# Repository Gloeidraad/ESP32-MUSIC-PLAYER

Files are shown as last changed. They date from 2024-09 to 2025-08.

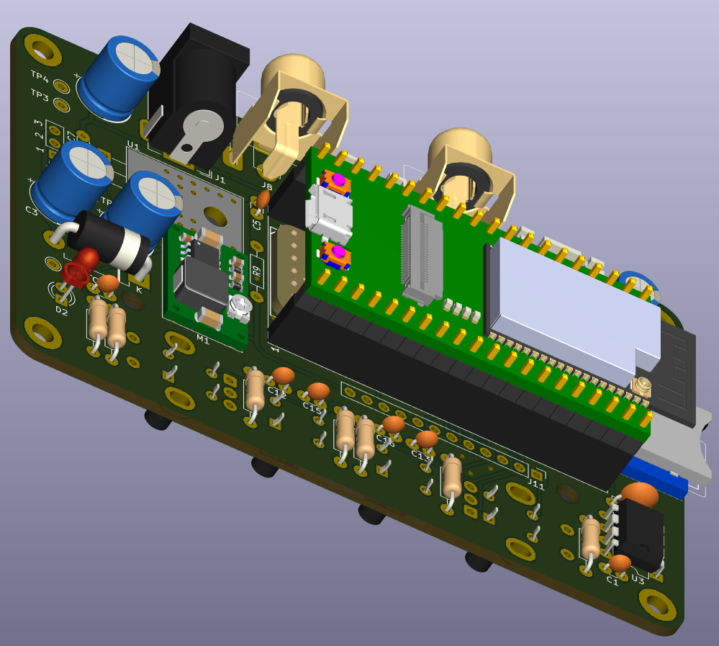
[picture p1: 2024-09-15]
Hardware/V1/Doc/Images/ESP32-MUSIC-PLAYER-V1-3D-2.png

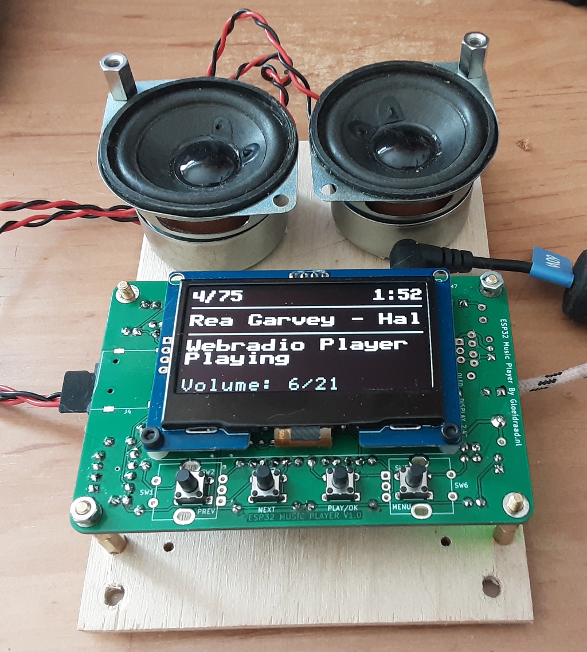
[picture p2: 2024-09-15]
Hardware/V1/Doc/Images/ESP32-MUSIC-PLAYER-V1-3D-DEMO.jpg

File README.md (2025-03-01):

# ESP32-MUSIC-PLAYER
SD-Card, Webradio, Bluetooth music player based on an ESP32 Wrover module

This is an MP3 player, Web-radio player, Bluetooth player, and simple waveform generator, based on an ESP32 WROVER module. The output can be either a line-out connection or an on-board 2 x 3W @ 4 ohms power ampifier. The output type can be chosen by mounting matching module(s).

This design is derived from my project "AM/FM-modulator-with-ESP32-module" (https://github.com/Gloeidraad/AMFM-modulator-with-ESP32-module). 

The PCB design has been made with KiCad 8.0. 

There at two versions of the design: 
Version 1.1 is mostly based on through hole components. It uses the I2C version of the 2.4 inch OLED display. Some examples can be found at: https://nl.aliexpress.com/item/1005006345983913.html choose the version with the connector on the top and left side of the display. It can be equipped with a PCM5102A Module for line out audio, or with one or two MAX98357A Module(s), allowing to connect directly to loudspeakers with a maximum power of 3 Watt per channel.  
The second version V1.5 is mostly based on 1206 SMD devices, and can be built into a cheap Strapubox 2515WS or the similar TRU COMPONENTS TC-2515 housing, available at https://www.conrad.com. This version uses the SPI version of 2.4 inch OLED display, and supports only audio line output via a PCM5102A Module. The display can also be found on : https://nl.aliexpress.com/item/1005006345983913.html but choose the version  the 7 pins connector on the left side of the display. This version can also be equipped with a SC card adapter, which allows the SD-card to be inserted next to the display. In addition, a nice front cover is available. Both the SD adapter and the front cover are included in the V1.5 design files.
The software will automatically detect, which display is attached, so there is only one version of the software. Please note, that the software supports only ASCII code page 437 (OEM-US, OEM 437, PC-8, or MS-DOS Latin US) up to character 0xAF, so if you enter names and titles with special characters, please be sure that the data is stored in this format. An example of the web radio play list can be found in the project.

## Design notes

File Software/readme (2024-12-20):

This sketch has been built with Arduino IDE 2.3.2 and ESP32 board package 2.0.17.

It should be no problem to use a newer or older IDE version, however these instructions
are for the 2.3.2 - 2.3.4 versions. Please note that the sketch will not run when
compiled with ESP32 board package 3.0.0 or higher.

Step 1: Download the Arduino IDE software from:
        https://www.arduino.cc/en/software
        (Possibly scroll down on the page for 2.3.2)
 
Step 2: Open Arduino IDE and install the ESP32 packages:
        https://randomnerdtutorials.com/installing-the-esp32-board-in-arduino-ide-windows-instructions/
        (Remark: the few seconds they mentioned to install the package is actually a couple of minutes, so be patient)

Step 3: Download the sketch, and make sure the whole
        project is inside the directory ESP32-Music-Player
        Open the directory and open project ESP32-Music-Player.ino
        
Step 4: Select the target board with menu:
        Tools => Board "xxx" => ESP32 Arduino => ESP32 Wrover Kit (all versions)
        
Step 5: Select the needed partition scheme with menu:
        Tools => Partition Scheme "xxx" => Huge APP (...)
        
Step 6: Switch on both “Show verbose output” checkboxes in menu:
        File => Preferences => tab Settings
        (Building the sketch takes a long time, so it is useful
        to monitor the progress)
        
Step 7: Connect the USB cable to the ESP32 module and make sure that
        the PC recognizes it as a serial port. If not, install the
        drivers for the corresponding serial adapter, normally
        CP2102,r CH340C, or CH9102
         
Step 8: Choose the port of the ESP32 module via menu:
        Tools => Port
         
Step 9: To see the debug info, you can open a serial monitor:
        Tools => Serial Monitor
        And set the baud rate to 115200
         
Step 10: Compile and upload the sketch:
         Sketch => Upload (or press the (->) button)
         It will take a while to compile the whole sketch,
         so have a little patience...
         
Step 11: You can monitor the messages from the sketch in the serial
         monitor, as long as the USB cable is connected. In addition,
         you can query some information by sending some simple commands.
         Send a ? to get a list of the commands.

Notes:

I used the following libaries for the project: 
 
https://github.com/schreibfaul1/ESP32-audioI2S/
https://github.com/pschatzmann/ESP32-A2DP
https://github.com/mathertel/OneButton

I included those used directories directly in the project. In the previous version
the libraries were installed separately, but it appeared that using a newer or older
versions of a library can lead to errors or unwanted behavior. Therefore, working
versions are included in the project (in subdirectory “src”). Please take care if
you plan to replace them with a different version.
          
Please report if you encounter any problems with the libraries.

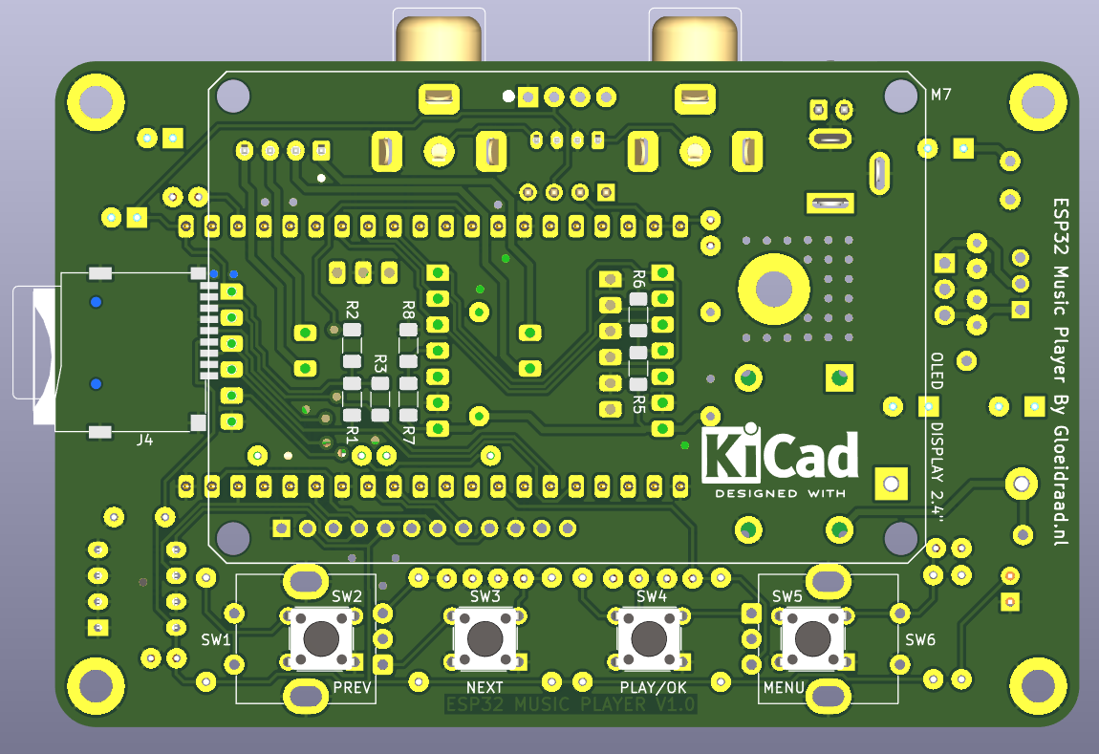
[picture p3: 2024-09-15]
Hardware/V1/Doc/Images/ESP32-MUSIC-PLAYER-V1-3D-BOT1.png

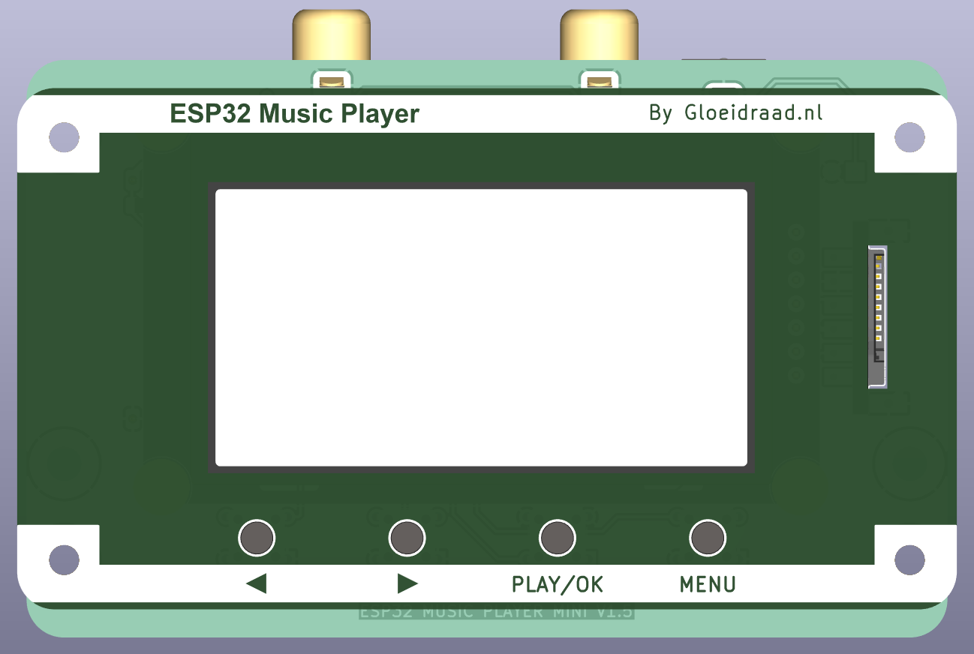
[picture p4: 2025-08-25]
Hardware/V5-SPI/ESP32-MUSIC-PLAYER-MINI-V5-PANEL/Images/assy front.png

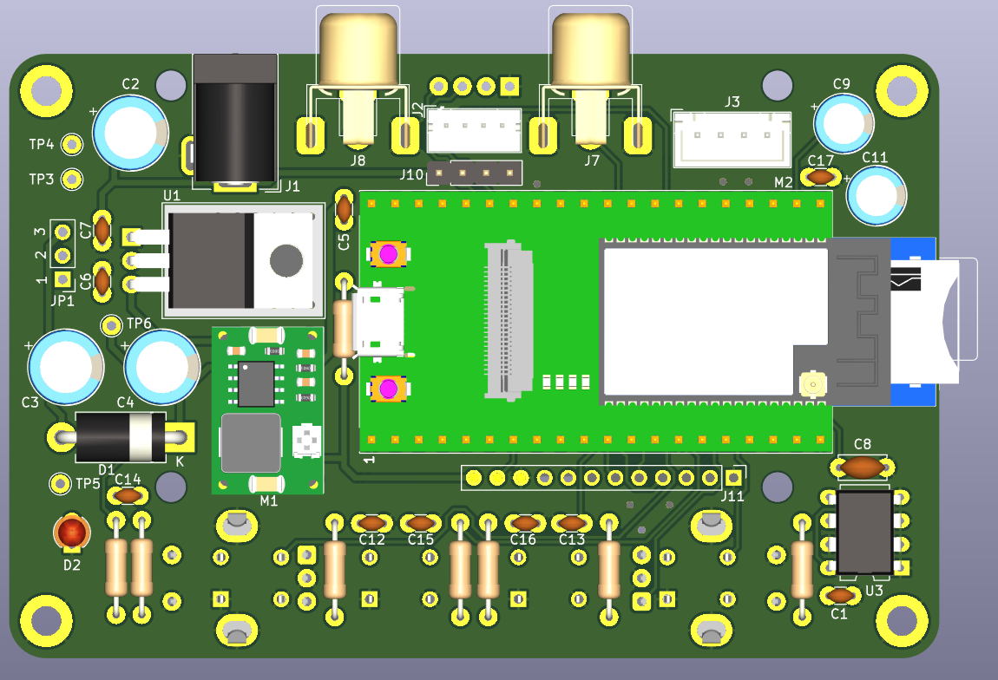
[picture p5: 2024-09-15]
Hardware/V1/Doc/Images/ESP32-MUSIC-PLAYER-V1-3D-TOP2.png

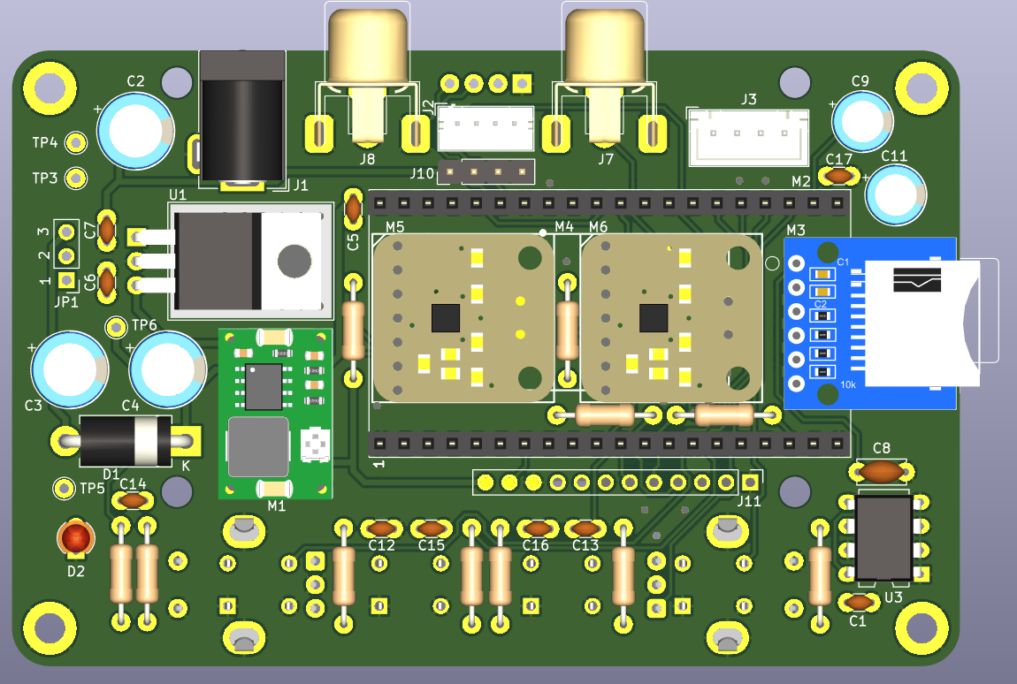
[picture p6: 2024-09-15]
Hardware/V1/Doc/Images/ESP32-MUSIC-PLAYER-V1-3D-TOP1.png

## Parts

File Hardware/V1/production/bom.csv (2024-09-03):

Designator | Footprint | Quantity | Value | LCSC Part #
C1, C5, C6, C7 | C_CER_D30_W16_P25_E20_H08 | 4 | 100n
C11, C9 | CE_Radial_D6.3mm_P2.50mm_E2.0mm | 2 | 10µF
C12, C13, C14, C15, C16, C17 | C_CER_D30_W16_P25_E20_H08 | 6 | 1n
C2, C3, C4 | CE_Radial_D8.0mm_P3.50mm_E2.0mm | 3 | 100µF
C8 | C_CER_D50_W25_P50_E20_H08 | 1 | 2u2
D1 | D_DO-201AD_P12.70mm_Horizontal | 1 | 1N5822
D2 | LED_D3.0mm | 1 | LED
J1 | BarrelJack_GCT_DCJ200-10-A_Horizontal | 1 | DC-IN
J10 | PinHeader_1x04_P2.54mm_Vertical | 1 | HDR4
J11 | PinHeader_1x12_P2.54mm_Vertical | 1 | EXP1
J2 | JST_PH_B4B-PH-K_1x04_P2.00mm_Vertical | 1 | JST PH4
J3 | JST_XH_B4B-XH-A_1x04_P2.50mm_Vertical | 1 | JST XH4
J4 | TF PUSH | 1 | SHOU-HAN-TF-PUSH | C393941
J7, J8 | Keystone RCA | 2 | Keystone 900
J9 | JST_EH_B2B-EH-A_1x02_P2.50mm_Vertical | 1 | Conn_01x02
JP1 | PinHeader_1x03_P2.54mm_Vertical | 1 | PSEL
M1 | MOD-DC-DC-DUAL | 1 | CN3903 5V/3A Module
M2 | ESP32-WROVER-DEV_ON_HEADERS_BARE | 1 | ESP32-WROVER-CAM-40P
M3 | MOD-USD-ADAPTER18X18 | 1 | µSD CARD MODULE
M4 | MOD-PCM5102A-TYPE2B | 1 | PCM5102A Module
M5, M6 | MOD-MAX98357A | 2 | MAX98357A Module
M7 | OLED128x64-2.4inch-i2c-top | 1 | OLED 2.4 inch
R1, R2, R3 | 1206 | 3 | 10k
R10 | R_Axial_L6.0mm_D2.0mm_P10.16mm_Horizontal | 1 | 560k
R11 | R_Axial_L6.0mm_D2.0mm_P10.16mm_Horizontal | 1 | 470R
R12, R13 | R_Axial_L6.0mm_D2.0mm_P10.16mm_Horizontal | 2 | 10k
R14, R16, R17, R18, R19, R20 | R_Axial_L6.0mm_D2.0mm_P10.16mm_Horizontal | 6 | 47k
R5, R6, R7, R8 | 1206 | 4 | NM
R9 | R_Axial_L6.0mm_D2.0mm_P10.16mm_Horizontal | 1 | 100k
SW1, SW6 | RotaryEncoder_Bourns_Vertical_PEC12R-3x17F-Sxxxx | 2 | RotaryEncoder_Switch
SW2, SW3, SW4, SW5 | SW_TH_Tactile_Omron_B3F-10xx | 4 | SW-PUSHBUT-6X6-V
TP3, TP4, TP5, TP6 | TestPoint_THTPad_D2.0mm_Drill1.0mm | 4 | TestPoint
U1 | TO-220-3_Horizontal_TabDown | 1 | L7818
U3 | DIP-SO-08_W7.62mm | 1 | 24LC64

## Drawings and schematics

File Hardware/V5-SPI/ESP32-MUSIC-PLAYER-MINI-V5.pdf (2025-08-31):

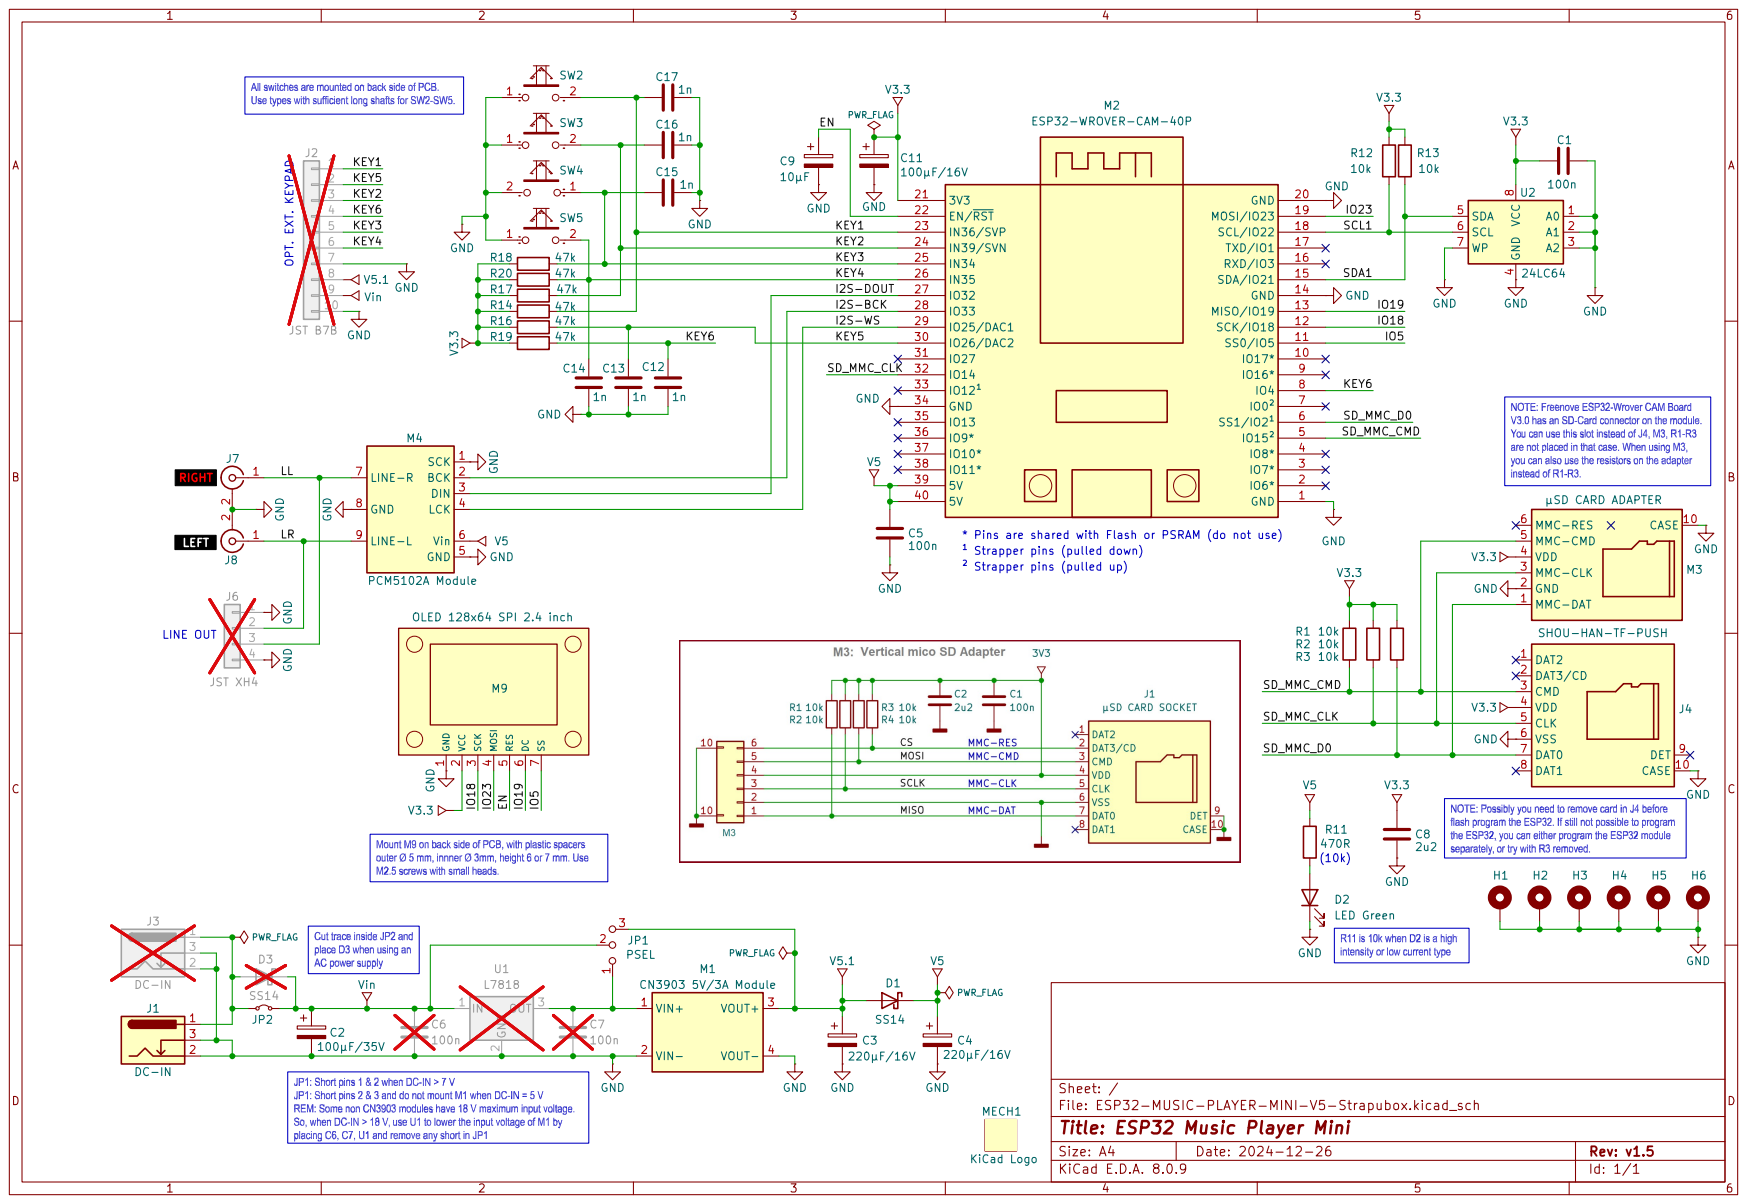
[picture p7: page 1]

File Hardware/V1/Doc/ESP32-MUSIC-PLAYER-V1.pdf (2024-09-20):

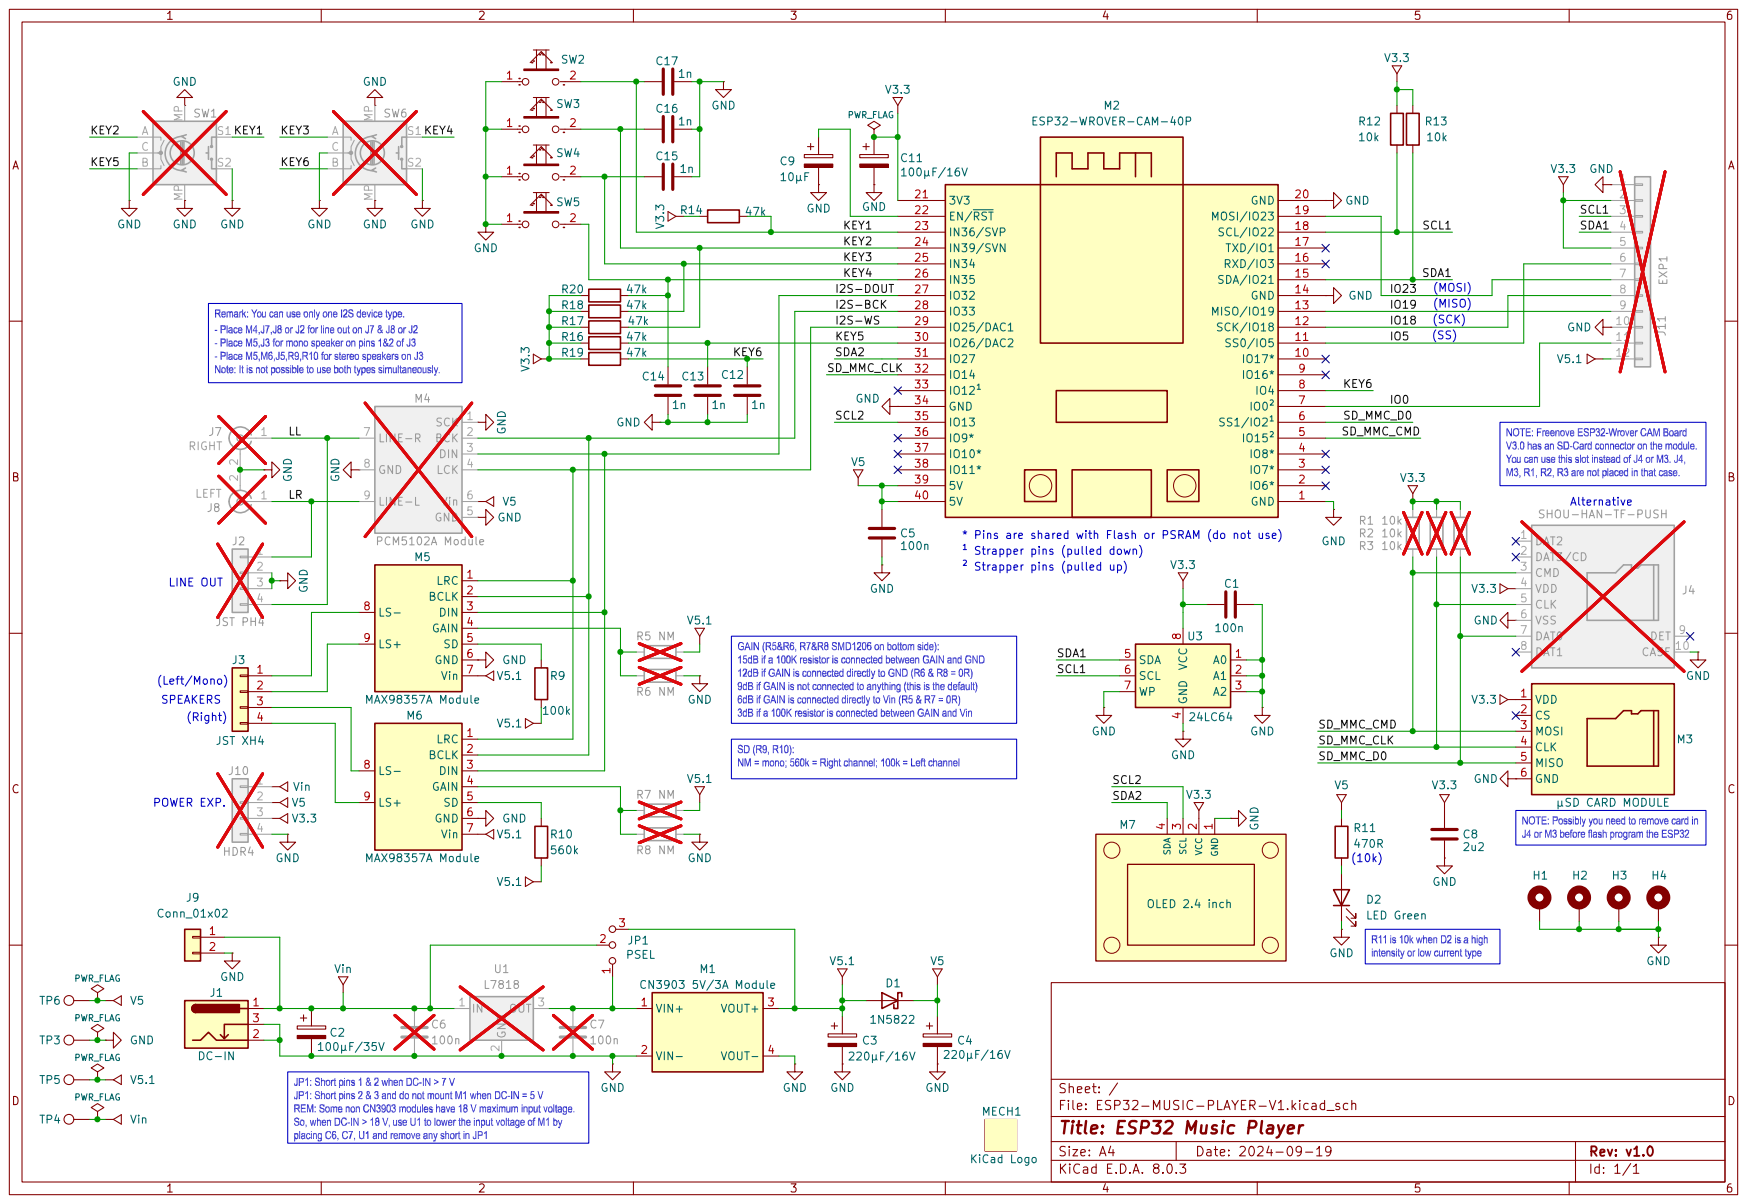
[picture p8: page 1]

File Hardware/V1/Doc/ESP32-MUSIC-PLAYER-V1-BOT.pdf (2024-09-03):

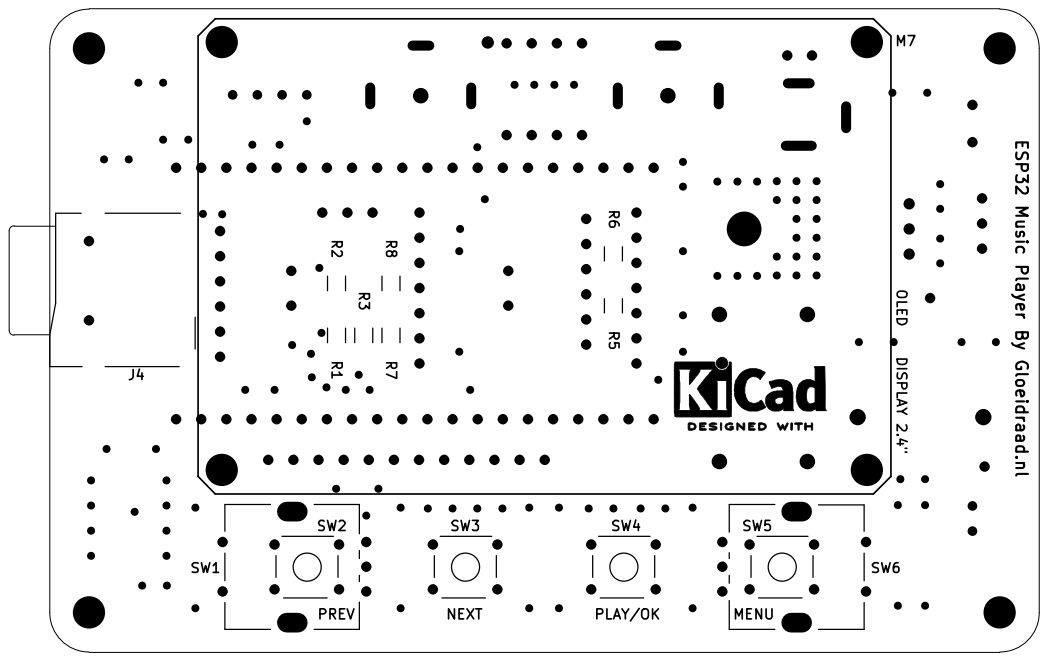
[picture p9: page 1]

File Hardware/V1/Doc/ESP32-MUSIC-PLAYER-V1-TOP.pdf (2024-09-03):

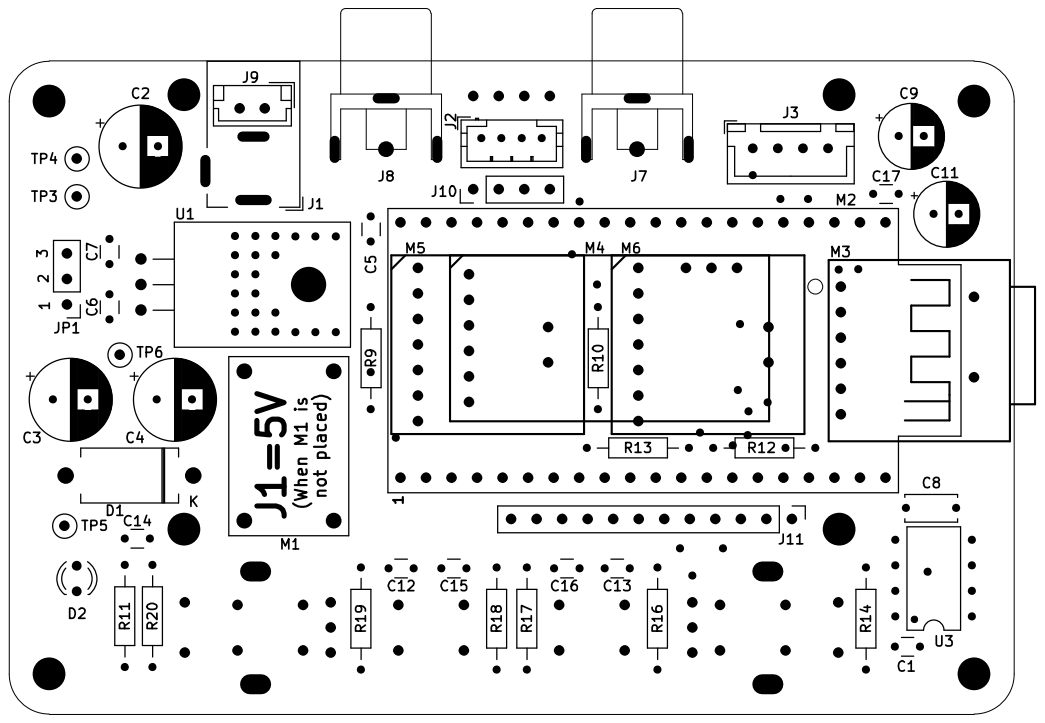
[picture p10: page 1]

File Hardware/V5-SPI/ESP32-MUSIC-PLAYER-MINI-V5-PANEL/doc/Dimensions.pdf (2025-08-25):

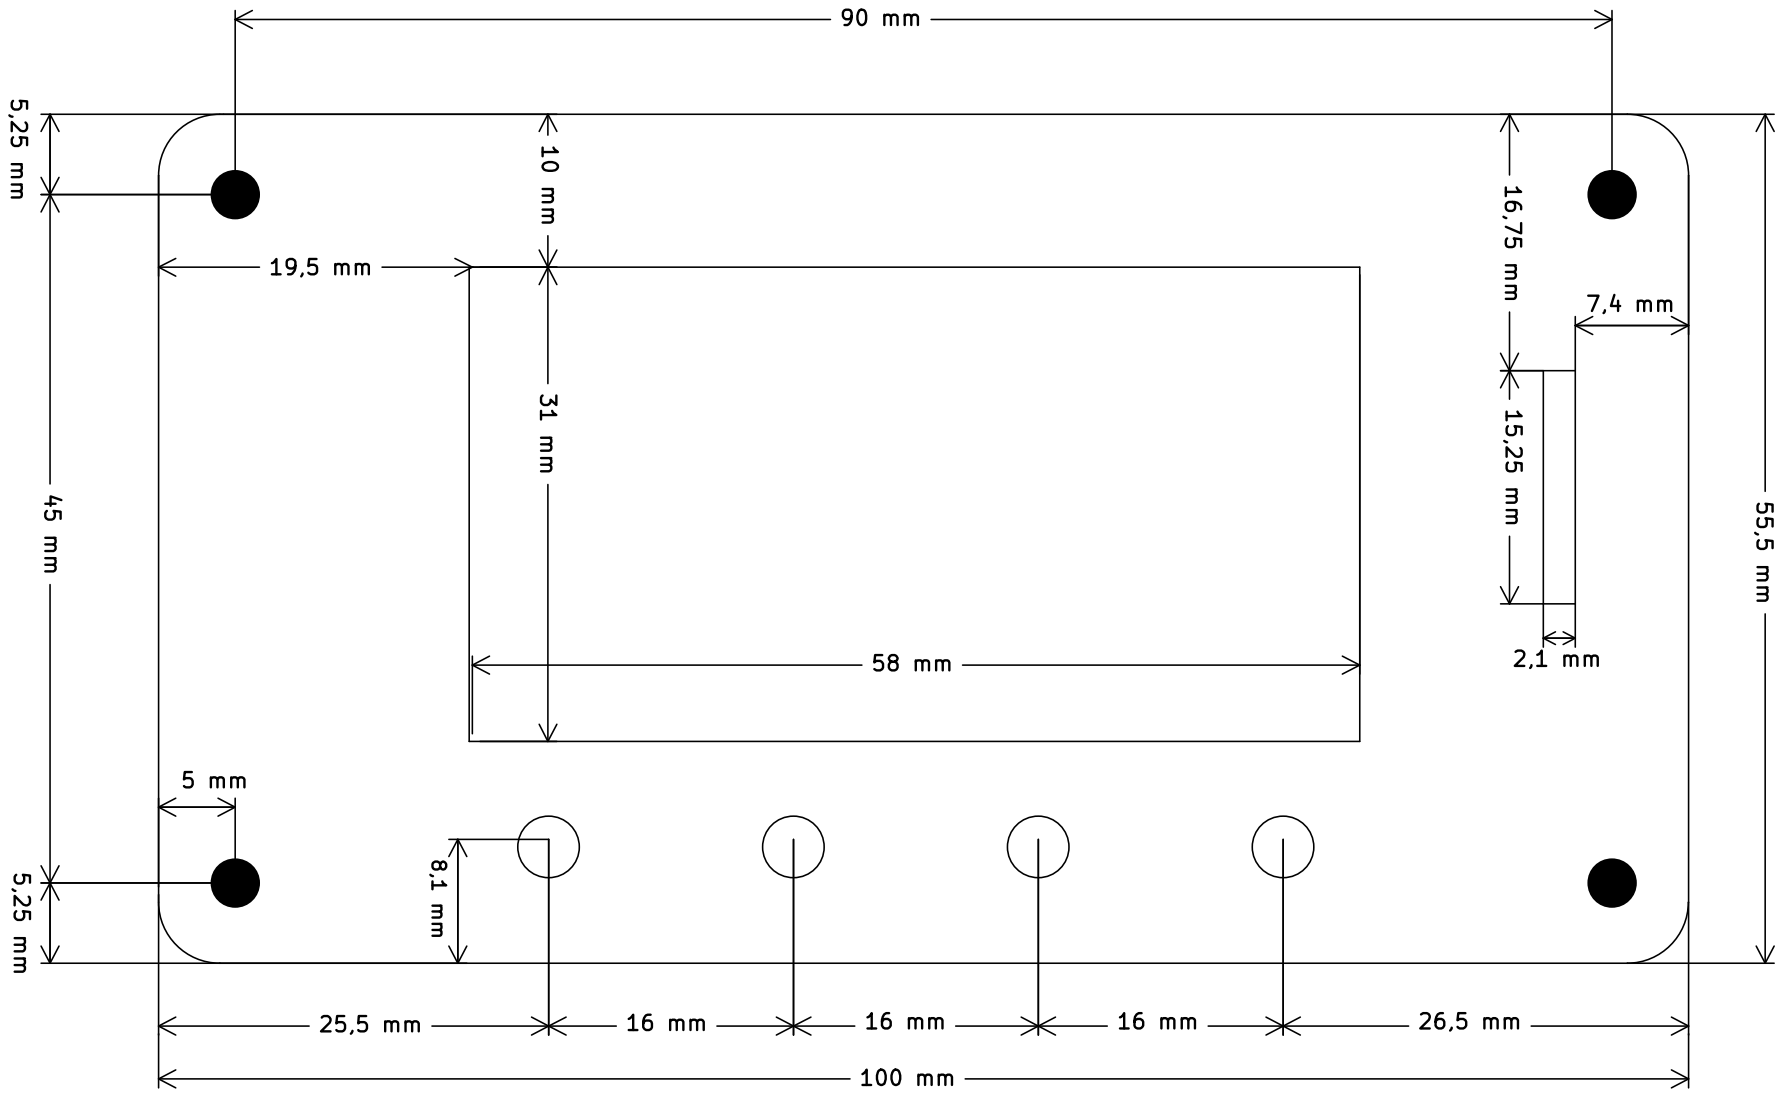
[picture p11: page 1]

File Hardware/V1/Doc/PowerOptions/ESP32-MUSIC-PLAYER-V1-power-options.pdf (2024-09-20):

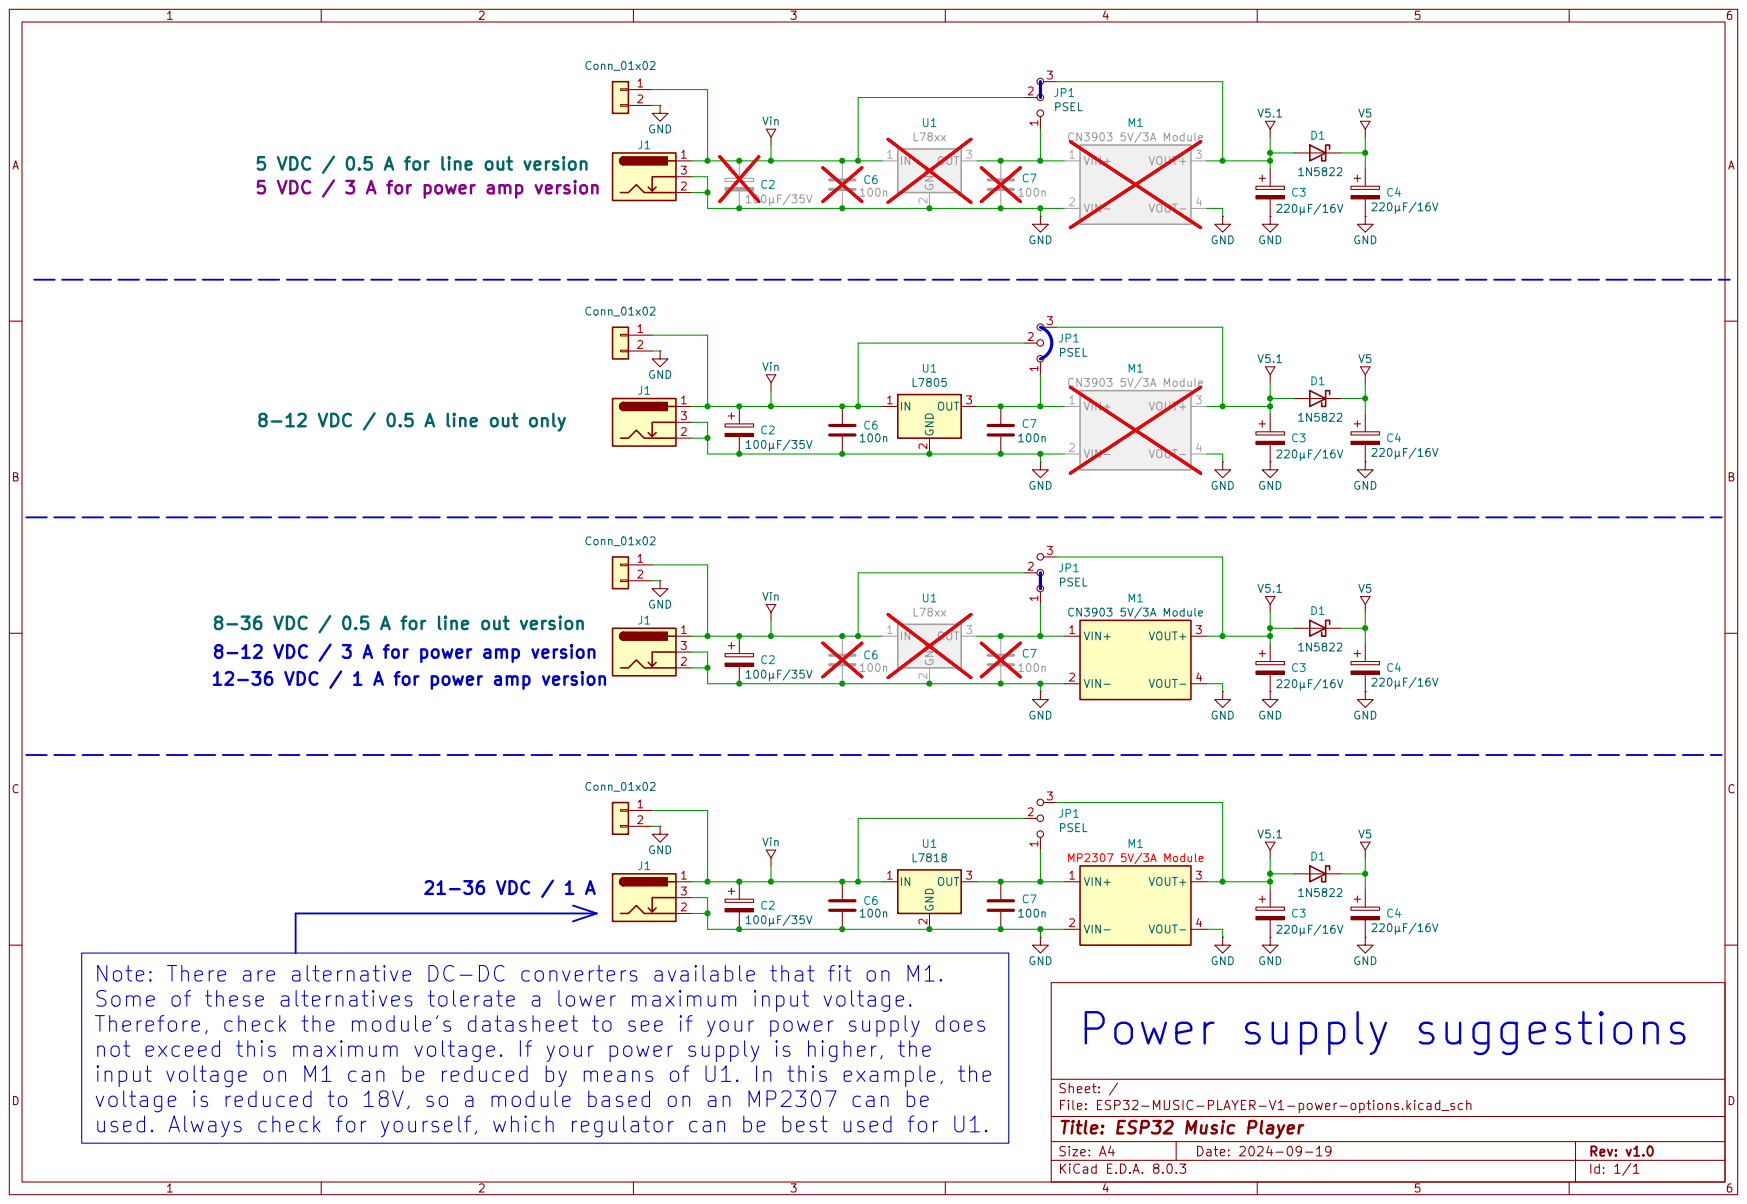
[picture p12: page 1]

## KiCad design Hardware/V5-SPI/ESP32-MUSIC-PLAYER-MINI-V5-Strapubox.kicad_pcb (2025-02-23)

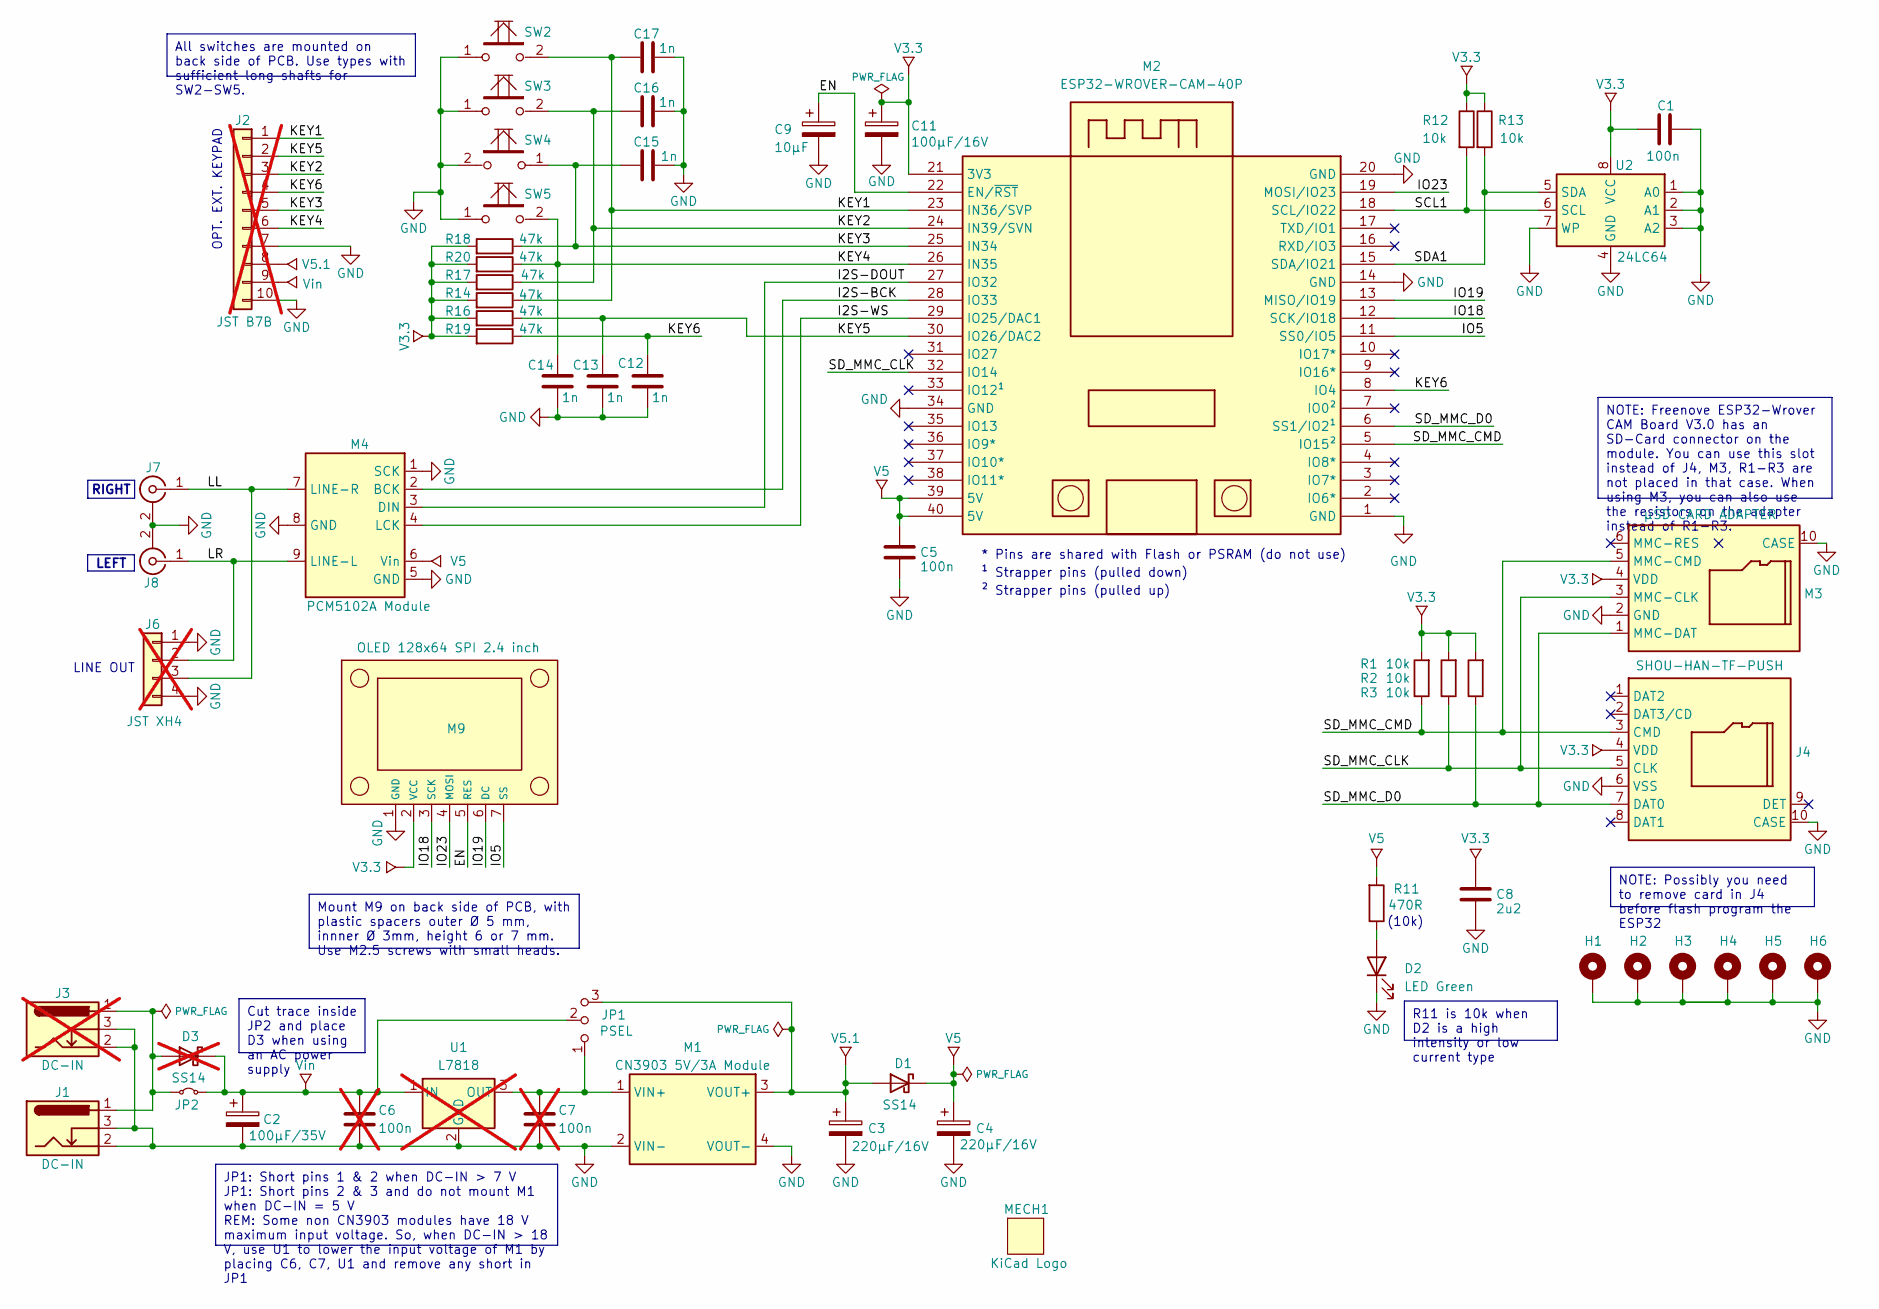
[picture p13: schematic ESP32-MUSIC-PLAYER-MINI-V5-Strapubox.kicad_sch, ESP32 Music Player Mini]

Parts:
C1, C5: 100n; C_1206_3216Metric_Pad1.33x1.80mm_HandSolder
C2: 100µF/35V; CE_Radial_D8.0mm_P3.50mm_E2.0mm
C3, C4: 220µF/16V; CE_Radial_D8.0mm_P3.50mm_E2.0mm
C6, C7: 100n; C_1206_3216Metric_Pad1.33x1.80mm_HandSolder; not fitted
C8: 2u2; C_1206_3216Metric_Pad1.33x1.80mm_HandSolder
C9: 10µF; CE_Radial_D6.3mm_P2.50mm_E2.0mm
C11: 100µF/16V; CE_Radial_D6.3mm_P2.50mm_E2.0mm
C12, C13, C14, C15, C16, C17: 1n; C_1206_3216Metric_Pad1.33x1.80mm_HandSolder
D1: SS14; DIODE_SMA
D2: LED Green; LED_D3.0mm
D3: SS14; DIODE_SMA; not fitted
H1, H2, H3, H4, H5, H6: MountingHole; MountingHole_3.7mm_Pad
J1: DC-IN; BarrelJack_GCT_DCJ200-10-A_Horizontal
J2: JST B7B; PinHeader_1x10_P2.54mm_Vertical; not fitted
J3: DC-IN; BarrelJack_GCT_DCJ200-10-A_Horizontal; not fitted
J4: SHOU-HAN-TF-PUSH; TF PUSH; JLC C393941
J6: JST XH4; JST_XH_B4B-XH-A_1x04_P2.50mm_Vertical; not fitted
J7, J8: Keystone 900; Keystone RCA
JP1: PSEL; SolderJumper-3_P1.3mm_Open_RoundedPad1.0x1.5mm
JP2: Jumper_2_Small_Bridged; SolderJumper-2_P1.3mm_Bridged_RoundedPad1.0x1.5mm
M1: CN3903 5V/3A Module; MOD-DC-DC-DUAL
M2: ESP32-WROVER-CAM-40P; ESP32-WROVER-DEV_ON_HEADERS_BARE
M3: µSD CARD ADAPTER; PinHeader_1x06_P2.54mm_SD_expander_socket_T3
M4: PCM5102A Module; MOD-PCM5102A-TYPE2B
M9: OLED 128x64 SPI 2.4 inch; OLED128x64-2.4inch-spi-type1
MECH1: KiCad Logo; KiCad-Logo2_6mm_SilkScreen
R1, R2, R3, R12, R13: 10k; R_1206_3216Metric_Pad1.30x1.75mm_HandSolder
R11: 470R; R_1206_3216Metric_Pad1.30x1.75mm_HandSolder
R14, R16, R17, R18, R19, R20: 47k; R_1206_3216Metric_Pad1.30x1.75mm_HandSolder
SW2, SW3, SW4, SW5: SW-PUSHBUT-6X6-V; SW_TH_Tactile_Omron_B3F-10xx
U1: L7818; TO-252-2; not fitted
U2: 24LC64; SO-8_3.9x4.9mm_P1.27mm

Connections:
/EN: C9.1, M2.22 (EN/~RST), M9.5 (RES)
/I2S-BCK: M2.28 (IO33), M4.2 (BCK)
/I2S-DOUT: M2.27 (IO32), M4.3 (DIN)
/I2S-WS: M2.29 (IO25/DAC1), M4.4 (LCK)
/IO5: M2.11 (SS0/IO5), M9.7 (SS)
/IO18: M2.12 (SCK/IO18), M9.3 (SCK)
/IO19: M2.13 (MISO/IO19), M9.6 (DC)
/IO23: M2.19 (MOSI/IO23), M9.4 (MOSI)
/KEY1: C17.1, J2.1, M2.23 (IN36/SVP), R14.1, SW2.2
/KEY2: C16.1, J2.3, M2.24 (IN39/SVN), R17.1, SW3.2
/KEY3: C15.1, J2.5, M2.25 (IN34), R18.1, SW4.1
/KEY4: C14.1, J2.6, M2.26 (IN35), R20.1, SW5.2
/KEY5: C13.1, J2.2, M2.30 (IO26/DAC2), R16.1
/KEY6: C12.1, J2.4, M2.8 (IO4), R19.1
/LL: J6.3, J7.1 (In), M4.7 (LINE-R)
/LR: J6.2, J8.1 (In), M4.9 (LINE-L)
/SCL1: M2.18 (SCL/IO22), R12.2, U2.6 (SCL)
/SDA1: M2.15 (SDA/IO21), R13.2, U2.5 (SDA)
/SD_MMC_CLK: J4.5 (CLK), M2.32 (IO14), M3.3 (MMC-CLK), R2.1
/SD_MMC_CMD: J4.3 (CMD), M2.5 (IO15²), M3.5 (MMC-CMD), R1.1
/SD_MMC_D0: J4.7 (DAT0), M2.6 (SS1/IO2¹), M3.1 (MMC-DAT), R3.1
GND: C1.2, C2.2, C3.2, C4.2, C5.2, C6.2, C7.2, C8.2, C9.2, C11.2, C12.2, C13.2, C14.2, C15.2, C16.2, C17.2, D2.1 (K), H1.1, H2.1, H3.1, H4.1, H5.1, H6.1, J1.2, J1.3, J2.7, J2.10, J3.2, J3.3, J4.6 (VSS), J4.10 (CASE), J6.1, J6.4, J7.2 (Ext), J8.2 (Ext), M1.2 (VIN-), M1.4 (VOUT-), M2.1 (GND), M2.14 (GND), M2.20 (GND), M2.34 (GND), M3.2 (GND), M3.10 (CASE), M4.1 (SCK), M4.5 (GND), M4.8 (GND), M9.1 (GND), SW2.1, SW3.1, SW4.2, SW5.1, U1.2 (GND), U2.1 (A0), U2.2 (A1), U2.3 (A2), U2.4 (GND), U2.7 (WP)
unnamed: D2.2 (A), R11.1
unnamed: D3.2 (A), J1.1, J3.1, JP2.1 (A)
unnamed: C7.1, JP1.1 (A), M1.1 (VIN+), U1.3 (OUT)
V3.3: C1.1, C8.1, C11.1, J4.4 (VDD), M2.21 (3V3), M3.4 (VDD), M9.2 (VCC), R1.2, R2.2, R3.2, R12.1, R13.1, R14.2, R16.2, R17.2, R18.2, R19.2, R20.2, U2.8 (VCC)
V5: C4.1, C5.1, D1.1 (K), M2.39 (5V), M2.40 (5V), M4.6 (Vin), R11.2
V5.1: C3.1, D1.2 (A), J2.8, JP1.3 (B), M1.3 (VOUT+)
Vin: C2.1, C6.1, D3.1 (K), J2.9, JP1.2 (C), JP2.2 (B), U1.1 (IN)

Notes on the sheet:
R11 is 10k when D2 is a high intensity or low current type
NOTE: Possibly you need to remove card in J4 before flash program the ESP32
All switches are mounted on back side of PCB. Use types with sufficient long shafts for SW2-SW5.
Mount M9 on back side of PCB, with plastic spacers outer Ø 5 mm, innner Ø 3mm, height 6 or 7 mm. Use M2.5 screws with small heads.
NOTE: Freenove ESP32-Wrover CAM Board V3.0 has an SD-Card connector on the module. You can use this slot instead of J4, M3, R1-R3 are not placed in that case. When using M3, you can also use the resistors on the adapter instead of R1-R3.
Cut trace inside JP2 and place D3 when using an AC power supply
JP1: Short pins 1 & 2 when DC-IN > 7 V JP1: Short pins 2 & 3 and do not mount M1 when DC-IN = 5 V REM: Some non CN3903 modules have 18 V maximum input voltage. So, when DC-IN > 18 V, use U1 to lower the input voltage of M1 by placing C6, C7, U1 and remove any short in JP1
² Strapper pins (pulled up)
* Pins are shared with Flash or PSRAM (do not use)
LINE OUT
OPT. EXT. KEYPAD
¹ Strapper pins (pulled down)
RIGHT
(10k)
LEFT

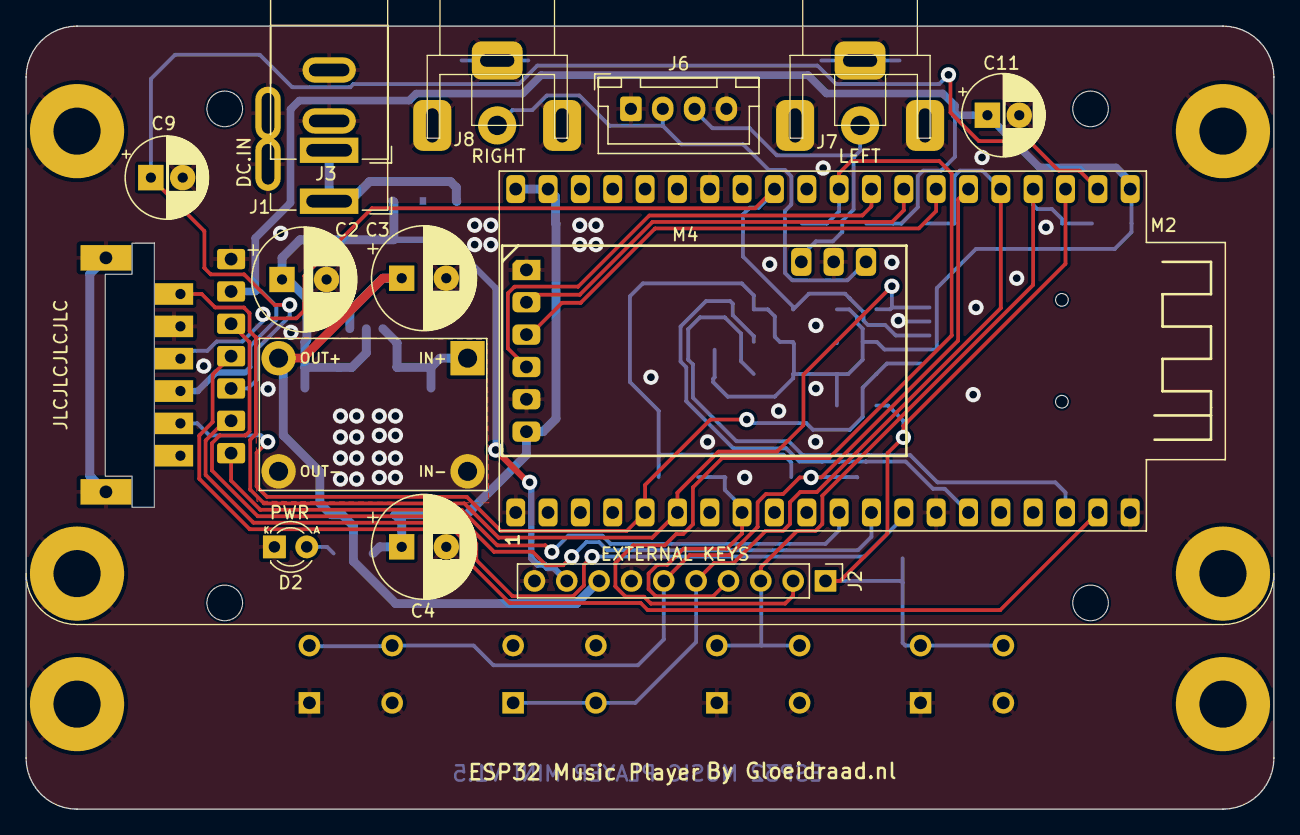
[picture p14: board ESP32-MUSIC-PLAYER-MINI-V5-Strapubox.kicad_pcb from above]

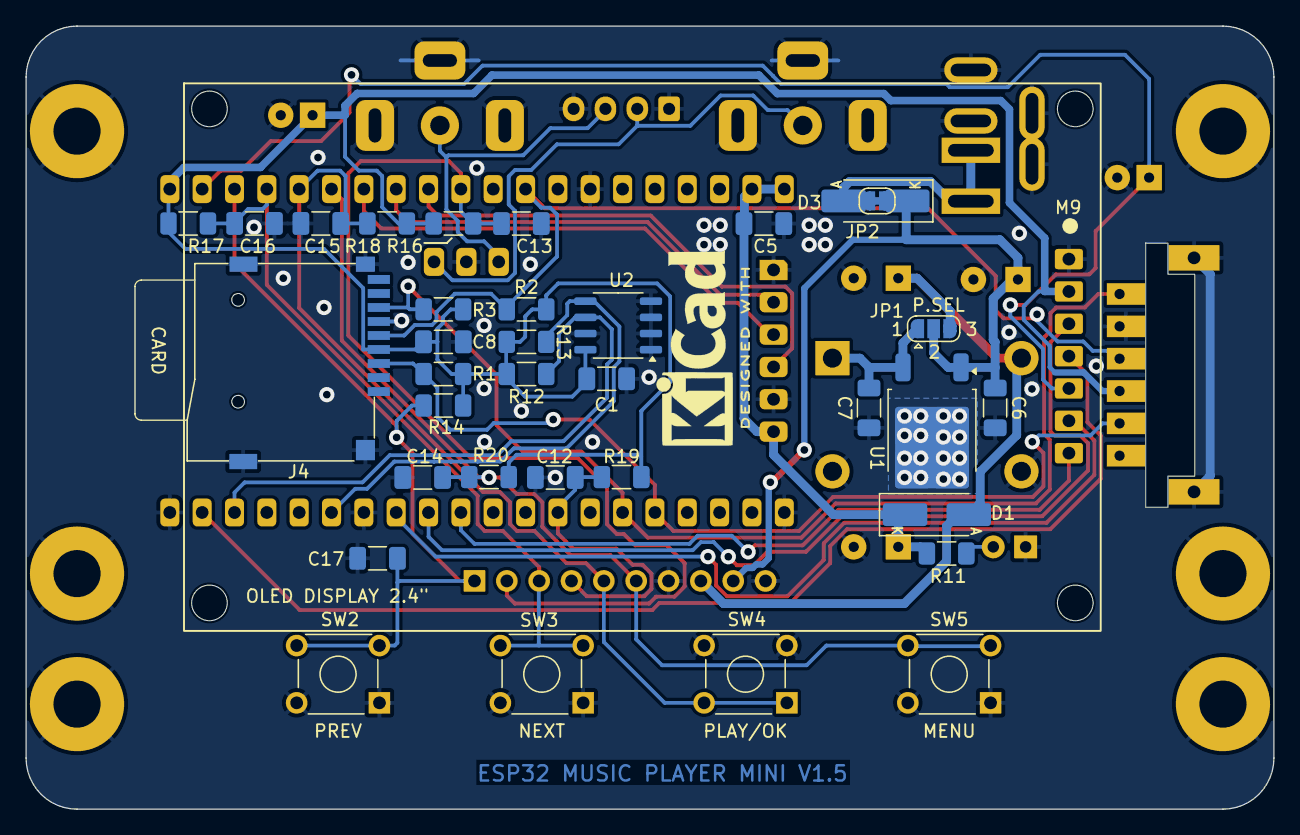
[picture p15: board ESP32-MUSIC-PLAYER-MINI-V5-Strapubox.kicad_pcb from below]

Board: 2 copper layers, 98.0 x 61.5 mm, 58 parts (37 on the bottom side), 29 nets.

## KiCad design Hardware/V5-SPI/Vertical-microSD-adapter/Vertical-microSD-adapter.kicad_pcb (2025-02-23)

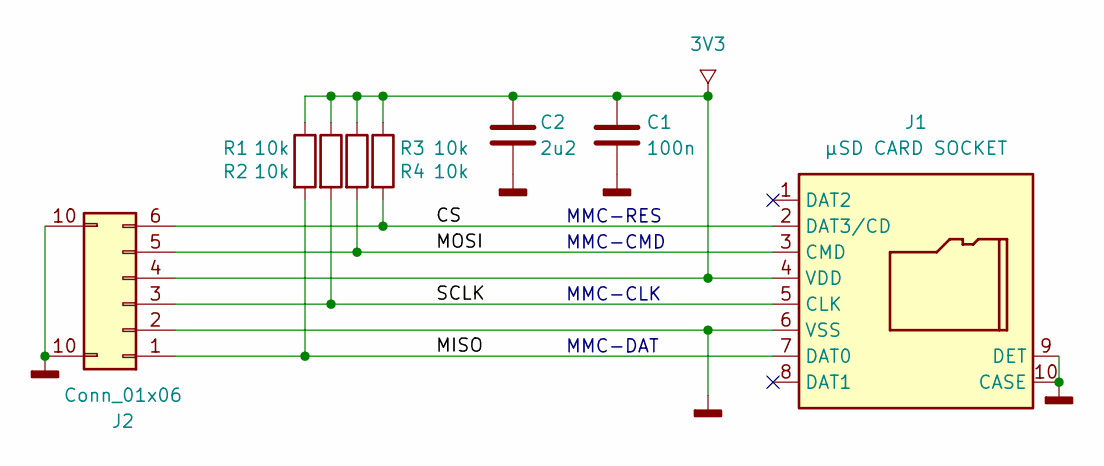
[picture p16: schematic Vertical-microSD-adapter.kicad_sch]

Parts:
C1: 100n; C_0603_1608Metric_Pad1.08x0.95mm_HandSolder
C2: 2u2; C_0805_2012Metric_Pad1.18x1.45mm_HandSolder
J1: µSD CARD SOCKET; TF PUSH
J2: Conn_01x06; PinHeader_1x06_P2.54mm_SD_expander
R1, R2, R3, R4: 10k; R_0603_1608Metric_Pad0.98x0.95mm_HandSolder

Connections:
3V3: C1.1, C2.1, J1.4 (VDD), J2.4, R1.1, R2.1, R3.1, R4.1
/CS: J1.2 (DAT3/CD), J2.6, R4.2
/MISO: J1.7 (DAT0), J2.1, R1.2
/MOSI: J1.3 (CMD), J2.5, R3.2
/SCLK: J1.5 (CLK), J2.3, R2.2
GNDD: C1.2, C2.2, J1.6 (VSS), J1.9 (DET), J1.10 (CASE), J2.2, J2.10 (Pin_10a)

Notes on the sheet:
MMC-CMD
MMC-DAT
MMC-CLK
MMC-RES

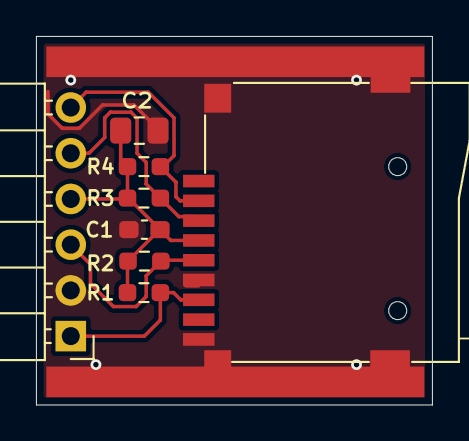
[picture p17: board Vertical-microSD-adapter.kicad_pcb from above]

Board: 2 copper layers, 22.0 x 20.5 mm, 8 parts (0 on the bottom side), 6 nets.

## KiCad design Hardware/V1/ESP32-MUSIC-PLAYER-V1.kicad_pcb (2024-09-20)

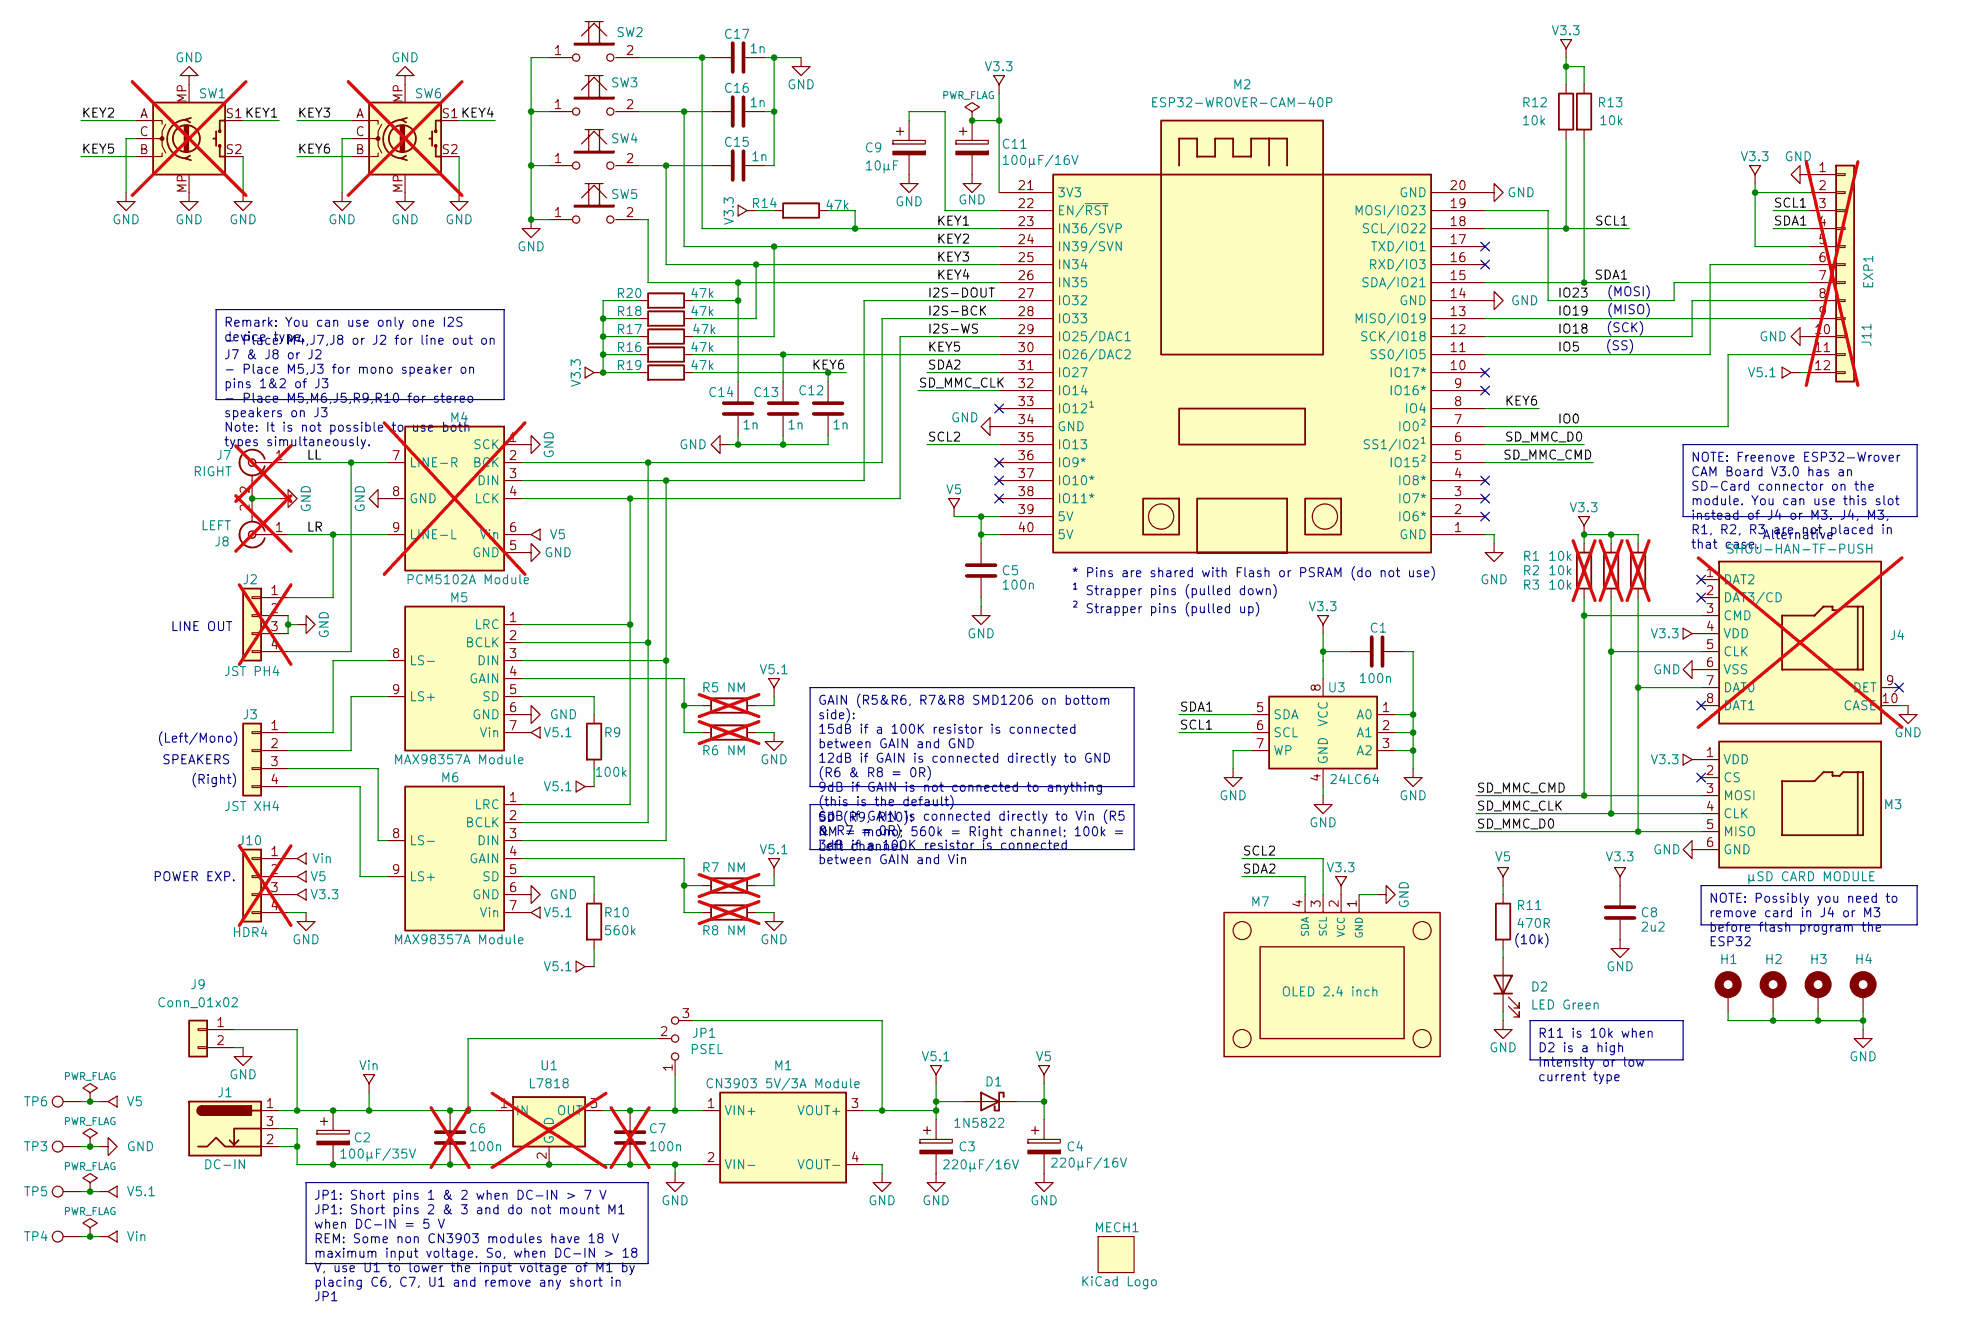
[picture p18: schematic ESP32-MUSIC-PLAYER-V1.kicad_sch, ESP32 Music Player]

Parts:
C1, C5: 100n; C_CER_D30_W16_P25_E20_H08
C2: 100µF/35V; CE_Radial_D8.0mm_P3.50mm_E2.0mm
C3, C4: 220µF/16V; CE_Radial_D8.0mm_P3.50mm_E2.0mm
C6, C7: 100n; C_CER_D30_W16_P25_E20_H08; not fitted
C8: 2u2; C_CER_D50_W25_P50_E20_H08
C9: 10µF; CE_Radial_D6.3mm_P2.50mm_E2.0mm
C11: 100µF/16V; CE_Radial_D6.3mm_P2.50mm_E2.0mm
C12, C13, C14, C15, C16, C17: 1n; C_CER_D30_W16_P25_E20_H08
D1: 1N5822; D_DO-201AD_P12.70mm_Horizontal
D2: LED Green; LED_D3.0mm
H1, H2, H3, H4: MountingHole; MountingHole_3.2mm_M3_DIN965_Pad
J1: DC-IN; BarrelJack_GCT_DCJ200-10-A_Horizontal
J2: JST PH4; JST_PH_B4B-PH-K_1x04_P2.00mm_Vertical; not fitted
J3: JST XH4; JST_XH_B4B-XH-A_1x04_P2.50mm_Vertical
J4: SHOU-HAN-TF-PUSH; TF PUSH; JLC C393941; not fitted
J7, J8: Keystone 900; Keystone RCA; not fitted
J9: Conn_01x02; JST_EH_B2B-EH-A_1x02_P2.50mm_Vertical
J10: HDR4; PinHeader_1x04_P2.54mm_Vertical; not fitted
J11: EXP1; PinHeader_1x12_P2.54mm_Vertical; not fitted
JP1: PSEL; PinHeader_1x03_P2.54mm_Vertical
M1: CN3903 5V/3A Module; MOD-DC-DC-DUAL
M2: ESP32-WROVER-CAM-40P; ESP32-WROVER-DEV_ON_HEADERS_BARE
M3: µSD CARD MODULE; MOD-USD-ADAPTER18X18
M4: PCM5102A Module; MOD-PCM5102A-TYPE2B; not fitted
M5, M6: MAX98357A Module; MOD-MAX98357A
M7: OLED 2.4 inch; OLED128x64-2.4inch-i2c-top
MECH1: KiCad Logo; KiCad-Logo2_6mm_SilkScreen
R1, R2, R3: 10k; R_1206_3216Metric_Pad1.30x1.75mm_HandSolder; not fitted
R5, R6, R7, R8: NM; R_1206_3216Metric_Pad1.30x1.75mm_HandSolder; not fitted
R9: 100k; R_Axial_L6.0mm_D2.0mm_P10.16mm_Horizontal
R10: 560k; R_Axial_L6.0mm_D2.0mm_P10.16mm_Horizontal
R11: 470R; R_Axial_L6.0mm_D2.0mm_P10.16mm_Horizontal
R12, R13: 10k; R_Axial_L6.0mm_D2.0mm_P10.16mm_Horizontal
R14, R16, R17, R18, R19, R20: 47k; R_Axial_L6.0mm_D2.0mm_P10.16mm_Horizontal
SW1, SW6: RotaryEncoder_Switch; RotaryEncoder_Bourns_Vertical_PEC12R-3x17F-Sxxxx; not fitted
SW2, SW3, SW4, SW5: SW-PUSHBUT-6X6-V; SW_TH_Tactile_Omron_B3F-10xx
TP3, TP4, TP5, TP6: TestPoint; TestPoint_THTPad_D2.0mm_Drill1.0mm
U1: L7818; TO-220-3_Horizontal_TabDown; not fitted
U3: 24LC64; DIP-SO-08_W7.62mm

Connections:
/I2S-BCK: M2.28 (IO33), M4.2 (BCK), M5.2 (BCLK), M6.2 (BCLK)
/I2S-DOUT: M2.27 (IO32), M4.3 (DIN), M5.3 (DIN), M6.3 (DIN)
/I2S-WS: M2.29 (IO25/DAC1), M4.4 (LCK), M5.1 (LRC), M6.1 (LRC)
/IO0: J11.11, M2.7 (IO0²)
/IO5: J11.6, M2.11 (SS0/IO5)
/IO18: J11.8, M2.12 (SCK/IO18)
/IO19: J11.9, M2.13 (MISO/IO19)
/IO23: J11.7, M2.19 (MOSI/IO23)
/KEY1: C17.1, M2.23 (IN36/SVP), R14.1, SW1.S1, SW2.2
/KEY2: C16.1, M2.24 (IN39/SVN), R17.1, SW1.A, SW3.2
/KEY3: C15.1, M2.25 (IN34), R18.1, SW4.2, SW6.A
/KEY4: C14.1, M2.26 (IN35), R20.1, SW5.2, SW6.S1
/KEY5: C13.1, M2.30 (IO26/DAC2), R16.1, SW1.B
/KEY6: C12.1, M2.8 (IO4), R19.1, SW6.B
/LL: J2.4, J7.1 (In), M4.7 (LINE-R)
/LR: J2.1, J8.1 (In), M4.9 (LINE-L)
/SCL1: J11.3, M2.18 (SCL/IO22), R12.2, U3.6 (SCL)
/SCL2: M2.35 (IO13), M7.3 (SCL)
/SDA1: J11.4, M2.15 (SDA/IO21), R13.2, U3.5 (SDA)
/SDA2: M2.31 (IO27), M7.4 (SDA)
/SD_MMC_CLK: J4.5 (CLK), M2.32 (IO14), M3.4 (CLK), R2.1
/SD_MMC_CMD: J4.3 (CMD), M2.5 (IO15²), M3.3 (MOSI), R1.1
/SD_MMC_D0: J4.7 (DAT0), M2.6 (SS1/IO2¹), M3.5 (MISO), R3.1
GND: C1.2, C2.2, C3.2, C4.2, C5.2, C6.2, C7.2, C8.2, C9.2, C11.2, C12.2, C13.2, C14.2, C15.2, C16.2, C17.2, D2.1 (K), H1.1, H2.1, H3.1, H4.1, J1.2, J1.3, J2.2, J2.3, J4.6 (VSS), J4.10 (CASE), J7.2 (Ext), J8.2 (Ext), J9.2, J10.4, J11.1, J11.10, M1.2 (VIN-), M1.4 (VOUT-), M2.1 (GND), M2.14 (GND), M2.20 (GND), M2.34 (GND), M3.6 (GND), M4.1 (SCK), M4.5 (GND), M4.8 (GND), M5.6 (GND), M6.6 (GND), M7.1 (GND), R6.2, R8.2, SW1.C, SW1.MP, SW1.S2, SW2.1, SW3.1, SW4.1, SW5.1, SW6.C, SW6.MP, SW6.S2, TP3.1, U1.2 (GND), U3.1 (A0), U3.2 (A1), U3.3 (A2), U3.4 (GND), U3.7 (WP)
unnamed: D2.2 (A), R11.2
unnamed: J3.1, M5.8 (LS-)
unnamed: J3.2, M5.9 (LS+)
unnamed: J3.3, M6.8 (LS-)
unnamed: J3.4, M6.9 (LS+)
unnamed: C7.1, JP1.1 (A), M1.1 (VIN+), U1.3 (OUT)
unnamed: C9.1, M2.22 (EN/~RST)
unnamed: M5.4 (GAIN), R5.1, R6.1
unnamed: M5.5 (SD), R9.1
unnamed: M6.4 (GAIN), R7.1, R8.1
unnamed: M6.5 (SD), R10.1
V3.3: C1.1, C8.1, C11.1, J4.4 (VDD), J10.3, J11.2, J11.5, M2.21 (3V3), M3.1 (VDD), M7.2 (VCC), R1.2, R2.2, R3.2, R12.1, R13.1, R14.2, R16.2, R17.2, R18.2, R19.2, R20.2, U3.8 (VCC)
V5: C4.1, C5.1, D1.1 (K), J10.2, M2.39 (5V), M2.40 (5V), M4.6 (Vin), R11.1, TP6.1
V5.1: C3.1, D1.2 (A), J11.12, JP1.3 (B), M1.3 (VOUT+), M5.7 (Vin), M6.7 (Vin), R5.2, R7.2, R9.2, R10.2, TP5.1
Vin: C2.1, C6.1, J1.1, J9.1, J10.1, JP1.2 (C), TP4.1, U1.1 (IN)

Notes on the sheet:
R11 is 10k when D2 is a high intensity or low current type
NOTE: Possibly you need to remove card in J4 or M3 before flash program the ESP32
Remark: You can use only one I2S device type.
GAIN (R5&R6, R7&R8 SMD1206 on bottom side): 15dB if a 100K resistor is connected between GAIN and GND 12dB if GAIN is connected directly to GND (R6 & R8 = 0R) 9dB if GAIN is not connected to anything (this is the default) 6dB if GAIN is connected directly to Vin (R5 & R7 = 0R) 3dB if a 100K resisto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
NOTE: Freenove ESP32-Wrover CAM Board V3.0 has an SD-Card connector on the module. You can use this slot instead of J4 or M3. J4, M3, R1, R2, R3 are not placed in that case.
- Place M4,J7,J8 or J2 for line out on J7 & J8 or J2 - Place M5,J3 for mono speaker on pins 1&2 of J3 - Place M5,M6,J5,R9,R10 for stereo speakers on J3 Note: It is not possible to use both types simultaneously.
SD (R9, R10): NM = mono; 560k = Right channel; 100k = Left channel
JP1: Short pins 1 & 2 when DC-IN > 7 V JP1: Short pins 2 & 3 and do not mount M1 when DC-IN = 5 V REM: Some non CN3903 modules have 18 V maximum input voltage. So, when DC-IN > 18 V, use U1 to lower the input voltage of M1 by placing C6, C7, U1 and remove any short in JP1
Alternative
² Strapper pins (pulled up)
* Pins are shared with Flash or PSRAM (do not use)
LINE OUT
(MISO)
(SS)
POWER EXP.
¹ Strapper pins (pulled down)
(SCK)
(10k)
(Right)
(MOSI)
SPEAKERS
(Left/Mono)

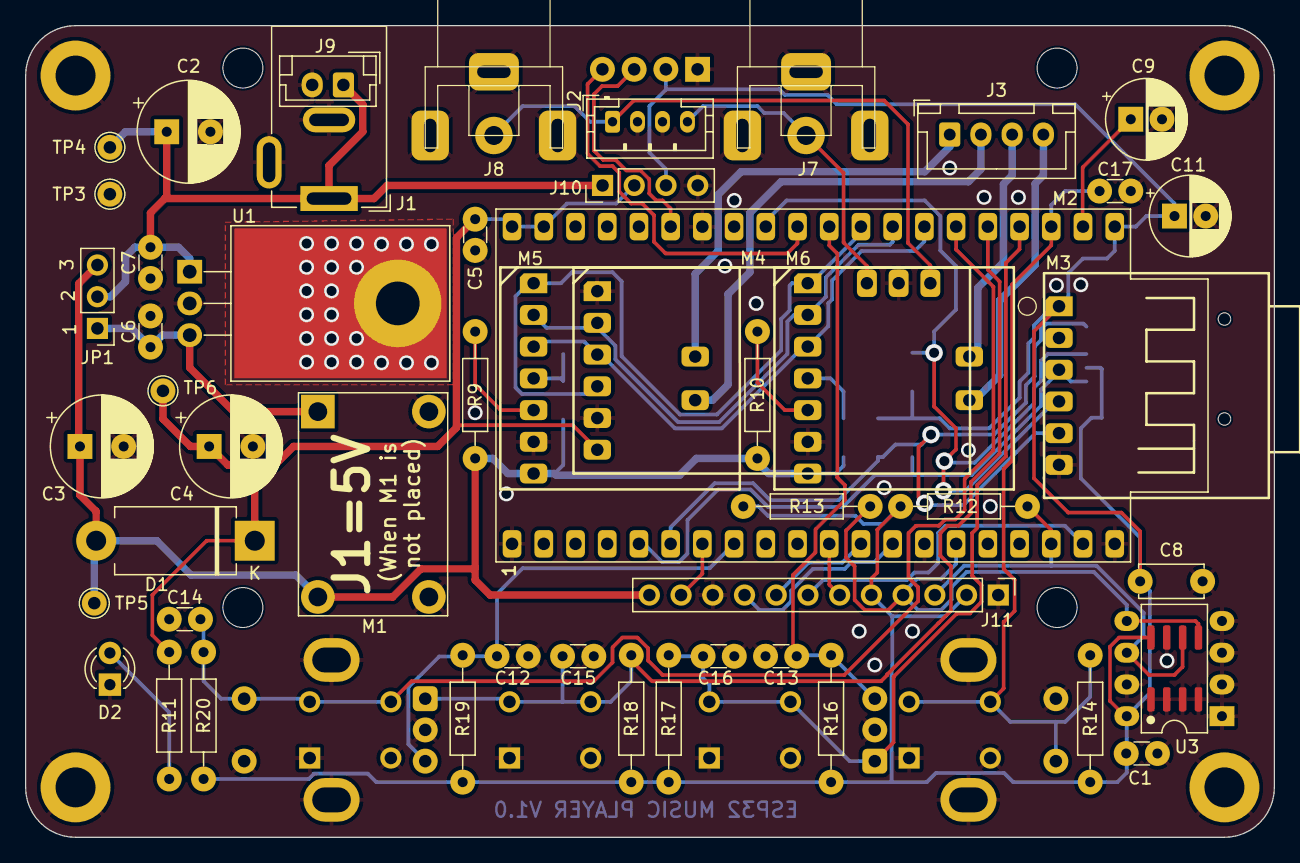
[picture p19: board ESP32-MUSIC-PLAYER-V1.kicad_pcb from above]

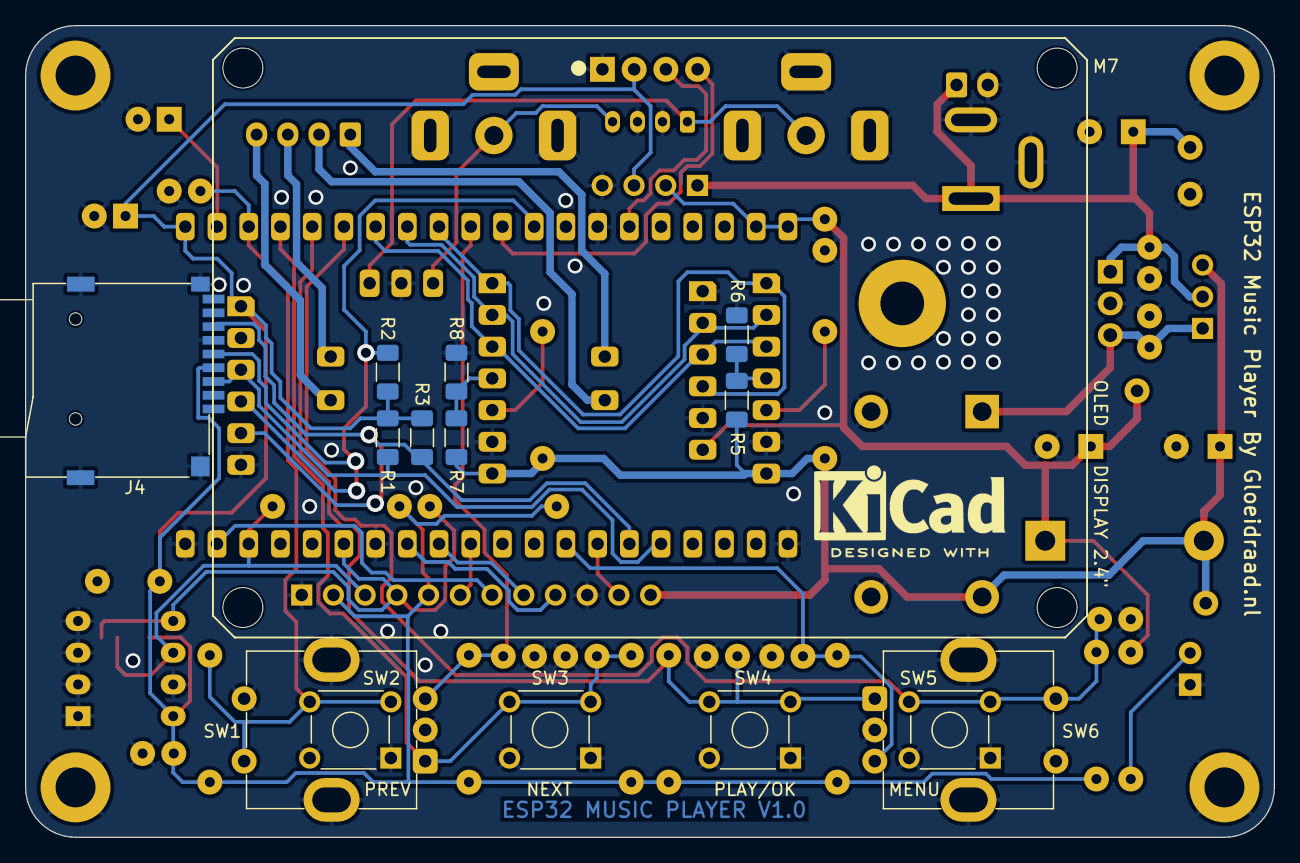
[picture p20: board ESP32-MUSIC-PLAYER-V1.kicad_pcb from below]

Board: 2 copper layers, 100.0 x 65.0 mm, 70 parts (16 on the bottom side), 39 nets.

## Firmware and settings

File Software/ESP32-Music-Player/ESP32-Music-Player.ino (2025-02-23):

// Increase size:
// https://github.com/espressif/arduino-esp32/issues/1906

#include <esp_idf_version.h>

#if ESP_IDF_VERSION < ESP_IDF_VERSION_VAL(5, 0, 0)  // ESP32 board package 3.0.0 or newer
  #warning unpack "AudioI2S-bsp-2xx.zip"       in directory "src"
  #warning unpack "BluetoothA2DP-bsp-2xx.zip"  in directory "src"
#else
  #warning unpack "AudioI2S-bsp-3xx.zip"       in directory "src"
  #warning unpack "BluetoothA2DP-bsp-3xx.zip"  in directory "src"
#endif

#include "src/AudioI2S/Audio.h"
#include "src/OneButton/OneButton.h"
#include "src/Hardware/board.h"
#include "src/Hardware/SSD1306.h"
#include "src/settings.h"
#include "src/ChipInfo.h" 
#include "src/I2C_Scanner.h"

#include "Player.h"
#include "Display.h"
#include "SimpleWaveGenerator.h"
#include "Gui.h"

SettingsClass      Settings(I2C_PORT_EEPROM, I2C_LOW_CLOCK_SPEED);

SsidSettingsClass  SsidSettings;
UrlSettingsClass   UrlSettings;
TrackSettingsClass TrackSettings;

PlayerClass        Player;
DisplayClass       Display;

SimpleWaveGeneratorClass WaveGenerator;

#define BLUETOOTH_FILE_NAME "bluetooth.ini"
#define SSID_FILE_NAME      "ssid.ini"
#define WEBRADIO_FILE_NAME  "webradio.ini"

OneButton SW1(PIN_SW1);
OneButton SW2(PIN_SW2);
OneButton SW3(PIN_SW3);
OneButton SW4(PIN_SW4);
OneButton SW5(PIN_SW5);

static void PrintWifiInfo() {
  char s[64];
   //WiFi.printDiag(Serial);
  sprintf(s, "WiFi TX level: %d (max %d = %sdB)", WiFi.getTxPower(), Settings.GetWifiTxLevel(), Settings.GetWifiTxLevelDB());
  Serial.println(s);
}

void SetWifiPower(int pwr, bool force = false) {
  if(!force && (pwr < 0 || pwr == Settings.NV.WifiTxIndex || pwr > SET_WIFI_TX_MAX)) {
    pwr = Settings.NV.WifiTxIndex;
    Serial.print("Wifi TX Power stays at ");
  }
  else {
    Settings.NV.WifiTxIndex = pwr;
    Serial.print("Changing Wifi TX Power to ");
    if (Settings.NV.SourceAF == SET_SOURCE_WEB_RADIO)
      WiFi.setTxPower((wifi_power_t)Settings.GetWifiTxLevel());
  }
  Serial.printf("entry %d (value %d = %sdB)\n",pwr, Settings.GetWifiTxLevel(), Settings.GetWifiTxLevelDB());
}

//=====================================================================//
//== Local: serial_command parser (for debugging purposes)           ==//
//=====================================================================//

static struct {
  const char * shortname;
  const char * longname;
  bool suppress_help;
} serial_command_list[] = {
  { "?",      "help"            , false }, // 0
  { "s",      "settings"        , false }, // 1
  { "rl",     "radiolist"       , false }, // 2
  { "rlr",    "radiolistraw"    , false }, // 3
  { "ssid",   "ssid"            , false }, // 4
  { "ssidpw", "ssidpassword"    , true  }, // 5
  { "tl",     "tracklist"       , false }, // 6
  { "pi",     "playinfo"        , false }, // 7
  { "sd",     "sd-card"         , false }, // 8
  { "wr",     "webradio"        , false }, // 9
  { "wf",     "waveform"        , false }, // 10
  { "bt",     "bluetooth"       , false }, // 11
  { "res",    "softreset"       , false }, // 12
  { "pw",     "printwaveform"   , false }, // 13
  { "pwh",    "printwaveformhex", false }, // 14
  { "sys",    "systeminfo"      , false }, // 15
  { "oled",   "oled-display"    , false }, // 16
  { "wifi",   "wifi-status"     , false }, // 17
  { "tx",     "wifi-tx-power"   , false }, // 18
  { "vol",    "volume"          , false }, // 19
  { "pp",     "play/pause"      , false }, // 20
  { "next",   "nexttrack"       , false }, // 21
  { "prev",   "prevtrack"       , false }, // 22
};

static void serial_command_help(void) {
  Serial.println("Short   | Long");
  Serial.println("--------|-------------");
  for (int i = 0; i < sizeof(serial_command_list) / sizeof(serial_command_list[0]); i++)
    if (!serial_command_list[i].suppress_help)
      Serial.printf("%-8s| %s\n", serial_command_list[i].shortname, serial_command_list[i].longname);
}

static int find_command_match(String &r) {
  for(int i = sizeof(serial_command_list) / sizeof(serial_command_list[0]) - 1; i >= 0 ; i--) {
    if(r.startsWith(serial_command_list[i].shortname) || r.startsWith(serial_command_list[i].longname)) {
      int len = r.indexOf(' ');
      if(len > 0) 
        r = r.substring(len + 1);
      return i;
    }
  }
  return -1;
}

static void change_player(uint8_t old_id, uint8_t new_id);

static void parse_command(String &r) { 
  r.trim();
  r.toLowerCase();
  int len = r.indexOf(' ');
  Serial.print("SERIAL COMMAND: ");
  Serial.println(r);
  switch(find_command_match(r)) {
    case  0: serial_command_help();     break;
    case  1: Settings.Print();          break;
    case  2: UrlSettings.Print(false);  break;
    case  3: UrlSettings.Print(true);   break;
    case  4: SsidSettings.Print(false); break;
    case  5: SsidSettings.Print(true);  break;
    case  6: TrackSettings.Print();     break;
    case  7: Player.SD_PrintDebug();    break;
    case  8: change_player(Settings.GetCurrentSourceId(), SET_SOURCE_SD_CARD);   break;
    case  9: change_player(Settings.GetCurrentSourceId(), SET_SOURCE_WEB_RADIO); break;
    case 10: change_player(Settings.GetCurrentSourceId(), SET_SOURCE_WAVE_GEN);  break;
    case 11: change_player(Settings.GetCurrentSourceId(), SET_SOURCE_BLUETOOTH); break;
    case 12: Settings.doSoftRestart();    break;
    case 13: Player.WP_PrintDebug(false); break;
    case 14: Player.WP_PrintDebug(true);  break;
    case 15: PrintChipInfo(0x0F);         break;
    case 16: OLED.Print();                break;
    case 17: PrintWifiInfo();             break;
    case 18: SetWifiPower(r.toInt());     break;
    case 19: { int vol = r.toInt();
               if(vol > 0)
                 Player.SetVolume(vol);
             }
             break;
    case 20: if(Settings.FirstTime) {
               Serial.println("FIRST TIME");    
               Settings.FirstSong = 1;
               Player.Play();
               Settings.FirstTime = 0;
             }
             else
               Player.PauseResume();
             break;
    case 21: Player.PlayNext();     break;
    case 22: Player.PlayPrevious(); break;
    default: Serial.println("Unknown Command"); break;
  }
}

//=====================================================================
//== Local: Timestamps
//=====================================================================

class TimeStampClass {
  public:
    TimeStampClass();
    void Update(void);
    uint32_t GetStamp10ms(void) { return timestamp_10ms;    }
    uint32_t GetStamp1sec(void) { return timestamp_1sec;    } 
    bool     Get10msTick(void)  { return ten_ms_tick;       }
    bool     GetSecondTick()    { return second_tick;       }
    bool     Get4SecTick()      { return four_seconds_tick; }
  private:
    uint64_t timestamp_us_prev;
    uint16_t timestamp_1sec_cnt;
    uint32_t timestamp_10ms;
    uint32_t timestamp_1sec;
    bool     ten_ms_tick;
    bool     second_tick;
    bool     four_seconds_tick;
};

TimeStampClass::TimeStampClass() {
  timestamp_10ms          = 0;
  timestamp_1sec          = 0;
  ten_ms_tick             = false;
  second_tick             = false;
  four_seconds_tick       = false;
  timestamp_us_prev       = 0;
  timestamp_1sec_cnt      = 0;
}

void TimeStampClass::Update(void) {
  uint64_t timestamp_us = esp_timer_get_time();
  ten_ms_tick             = false;
  second_tick             = false;
  four_seconds_tick       = false;
  if(timestamp_us - timestamp_us_prev >= TIMESTAMP_10MS_DIV) {
    timestamp_10ms++;
    timestamp_1sec_cnt++;
    timestamp_us_prev += TIMESTAMP_10MS_DIV;
    if(timestamp_us - timestamp_us_prev < TIMESTAMP_10MS_DIV) // supress multiple ticks 
      ten_ms_tick = true; 
    if(timestamp_1sec_cnt == 100) {
      timestamp_1sec++;
      timestamp_1sec_cnt = 0;
      second_tick = true;
      four_seconds_tick = !(timestamp_1sec & 3);
    }
  }
}

TimeStampClass TimeStamps;

//=====================================================================//
//== Local: Read setup and track data from SD Card                   ==//
//=====================================================================//

// MMC-SD: see https://github.com/espressif/arduino-esp32/tree/master/libraries/SD_MMC/src

static bool ReadSetupFromCard(bool get_init_data = true) {
  if(Settings.NV.SourceAF == SET_SOURCE_WAVE_GEN) return true; // Nothing to load for waveform player
  #ifdef USE_SD_MMC
    if(!SD_MMC.begin( "/sdcard", true)) {
      Serial.println("Card Mount Failed, using SSID & Radio lists from EEPROM");
      Settings.NoCard = 1;
      return false;
    }
  #else
    if (!SD.begin(PIN_SPI_SS, SPI, SPI_SD_SPEED)) {
      Serial.println("Card Mount Failed, using SSID & Radio lists from EEPROM");
      Settings.NoCard = 1;
      return false;
    }
  #endif
  Serial.println("Card Mount Succeeded");
  Settings.NoCard = 0;
  switch(Settings.NV.SourceAF) {
    case SET_SOURCE_SD_CARD   : TrackSettings.LoadFromCard();
                                break;
    case SET_SOURCE_WEB_RADIO : if(!SsidSettings.LoadFromCard(SSID_FILE_NAME))
                                  Serial.println("Using SSID list from EEPROM");
                                if(!UrlSettings.LoadFromCard(WEBRADIO_FILE_NAME))
                                  Serial.println("Using web station list from EEPROM");
                                break;
    case SET_SOURCE_BLUETOOTH : if(!Settings.LoadFromCard(BLUETOOTH_FILE_NAME))
                                  Serial.println("Using Bluetooth ID from EEPROM");
                                break;
  }
  #ifdef USE_SD_MMC
    SD_MMC.end(); // webradio doesn't like a mounted SD Card
  #else
    SD_MMC.end(); // webradio doesn't like a mounted SD Card
  #endif
  return true;
}

//=====================================================================//
//== Local: change player                                            ==//
//=====================================================================//

static void change_player(uint8_t old_id, uint8_t new_id) {
  if(new_id != old_id) {
    Serial.print("Change Player from \"");
    Serial.print(Settings.GetSourceName(old_id));
    Serial.print("\" to \"");
    Serial.print(Settings.GetSourceName(new_id));
    Serial.println("\"");
    Player.Stop();
    Settings.Play = 0;
    Settings.NV.SourceAF = new_id;
    Display.ShowBaseScreen(DISPLAY_HELP_PLEASE_WAIT);
    delay(100); // Give threads in Stop() some time to die out properly
    Settings.doSoftRestart();
  }
}

static void change_player(bool prev) {
  uint8_t CurrentSourceId = Settings.GetCurrentSourceId();
  if(prev) Settings.PrevPlayer();
  else     Settings.NextPlayer();
  change_player(CurrentSourceId, Settings.GetCurrentSourceId());
}

//=====================================================================//
//== Local: Loop function for Settings (keeps audio running)         ==//
//=====================================================================//

void SettingsLoopFunction(void) { Player.loop(); }

//=====================================================================//
//== Local: Button handlers                                          ==//
//=====================================================================//

static void GUI_Handler(uint8_t key) {
  if(key != 0xFF) Serial.printf("Button %d pressed: ", key);
  #if 1
  switch(GuiCallback(key)) {
    case GUI_RESULT_NEW_TRACK      : Player.PlayNew();      break;
    case GUI_RESULT_NEXT_PLAY      : Player.PlayNext();     break;
    case GUI_RESULT_PREV_PLAY      : Player.PlayPrevious(); break;
    case GUI_RESULT_PAUSE_PLAY     : if(Settings.FirstTime) {
                                       Serial.println("FIRST TIME");    
                                       Settings.FirstSong = 1;
                                       Player.Play();
                                       Settings.FirstTime = 0;
                                     }
                                     else
                                       Player.PauseResume();
                                     break;
    case GUI_RESULT_SEEK_PLAY      : Player.PositionEntry(); break;
    //case GUI_RESULT_STOP_PLAY    : break;
    //case GUI_RESULT_START_PLAY   : break;
    case GUI_RESULT_NEW_SSID       : Player.NewSsid(); break;
    case GUI_RESULT_NEW_AF_SOURCE  : change_player(Settings.NV.SourceAF, Settings.NewSourceAF); break;
    case GUI_RESULT_NEW_WIFI_TX_LEVEL : SetWifiPower(Settings.NV.WifiTxIndex, true); break;
    case GUI_RESULT_NEW_BT_TX_LEVEL   : /*SetBtPower(Settings.NV.BtTxIndex, true);*/ break;
    case GUI_RESULT_NEW_VOLUME     : Player.SetVolume(Settings.NV.Volume); break;
    case GUI_RESULT_OUTPUT_FORMAT  : Player.UpdateOutputFormat(); break;
    default: break;
  }
  #endif
  if(key != 0xFF) Serial.println();
}

static void SW1_HandleClick(void)     { GUI_Handler(KEY_SPARE);   } 
static void SW2_HandleClick(void)     { GUI_Handler(KEY_DN);      }
static void SW2_HandleLongClick(void) { GUI_Handler(KEY_LONG_DN); }
static void SW3_HandleClick(void)     { GUI_Handler(KEY_UP);      }
static void SW3_HandleLongClick(void) { GUI_Handler(KEY_LONG_UP); }
static void SW4_HandleClick(void)     { GUI_Handler(KEY_OK);      }
static void SW5_HandleClick(void)     { GUI_Handler(KEY_MENU);    }

//=====================================================================//
//== Local: Housekeeping, fix things that might go wrong in time     ==//
//=====================================================================//

static void Housekeeping(void) {
 }

//=====================================================================//
//== Main Set-up                                                     ==//
//=====================================================================//
//
// It appears that switching to another player cannot be done dynamically.
// Some parts of the player seems not to be cleaned up properly, so the new
// player will not work, or is unstable. Therefore, the solution is to do a
// soft restart to assure the player get a fresh end clean environment.

void setup(void) {
  bool oled_i2c_present;
  //Serial
  Serial.begin(SERIAL_BAUD_RATE);

  //SD(SPI)
  #ifdef USE_SD_MMC
    pinMode(SD_MMC_D0, INPUT_PULLUP);
    SD_MMC.setPins(SD_MMC_CLK,SD_MMC_CMD, SD_MMC_D0);
  #else
    pinMode(PIN_SPI_SS, OUTPUT);
    digitalWrite(PIN_SPI_SS, HIGH);
    SPI.begin(PIN_SPI_SCK, PIN_SPI_MISO, PIN_SPI_MOSI);
    SPI.setFrequency(1000000);
  #endif
#if OLED_DUAL_TARGET_PORT
  I2C_PORT_OLED.begin(PIN_SDA2, PIN_SCL2, I2C_HIGH_CLOCK_SPEED);
  oled_i2c_present = Scan_I2C_Device(I2C_PORT_OLED, OLED_I2C_ADDRESS);
  if(oled_i2c_present) {
    Serial.printf("OLED on I2C bus address 0x%02X found.\n", OLED_I2C_ADDRESS); 
    I2C_PORT_OLED.setBufferSize(256 + 8);
  }
  else {
    I2C_PORT_OLED.end();
    Serial.printf("OLED on I2C bus address 0x%02X not found; using SPI bus.\n", OLED_I2C_ADDRESS); 
    pinMode(PIN_CS, OUTPUT);
    pinMode(PIN_DC, OUTPUT);
    digitalWrite(PIN_CS, HIGH);
    digitalWrite(PIN_DC, HIGH);
    SPI_PORT_OLED.begin(PIN_SCLK, PIN_MISO, PIN_MOSI);
    SPI_PORT_OLED.setFrequency(SPI_OLED_CLOCK_SPEED);
  }
#else
  #ifdef I2C_PORT_OLED
    I2C_PORT_OLED.begin(PIN_SDA2, PIN_SCL2, I2C_HIGH_CLOCK_SPEED);
    I2C_PORT_OLED.setBufferSize(256 + 8);
    oled_i2c_present = true;
  #else
    pinMode(PIN_CS, OUTPUT);
    pinMode(PIN_DC, OUTPUT);
    digitalWrite(PIN_CS, HIGH);
    digitalWrite(PIN_DC, HIGH);
    SPI_PORT_OLED.begin(PIN_SCLK, PIN_MISO, PIN_MOSI);
    SPI_PORT_OLED.setFrequency(SPI_OLED_CLOCK_SPEED);
    oled_i2c_present = false;
  #endif
#endif
  I2C_PORT_EEPROM.begin(PIN_SDA1, PIN_SCL1, I2C_LOW_CLOCK_SPEED);
  I2C_PORT_EEPROM.setBufferSize(256 + 8);

  // Buttons
  Settings.BootKeys = 0;
  if(digitalRead(PIN_SW1) == LOW) Settings.BootKeys |= BOOT_KEY1_MASK;
  if(digitalRead(PIN_SW2) == LOW) Settings.BootKeys |= BOOT_KEY2_MASK;
  if(digitalRead(PIN_SW3) == LOW) Settings.BootKeys |= BOOT_KEY3_MASK;
  if(digitalRead(PIN_SW4) == LOW) Settings.BootKeys |= BOOT_KEY4_MASK;
  if(digitalRead(PIN_SW5) == LOW) Settings.BootKeys |= BOOT_KEY5_MASK;
  Serial.printf("Button boot keys pressed at startup 0x%02X \n", Settings.BootKeys);

  SW1.attachClick(SW1_HandleClick);
  SW2.attachClick(SW2_HandleClick);
  SW2.attachLongPressStart(SW2_HandleLongClick);
  SW3.attachClick(SW3_HandleClick);
  SW3.attachLongPressStart(SW3_HandleLongClick);
  SW4.attachClick(SW4_HandleClick);
  SW5.attachClick(SW5_HandleClick);

  if (Settings.BootKeys == 0x12) { // UP & MENU
    Settings.EepromErase();        // Use this when settings have got corrupted
  }
  Settings.EepromLoad();           // Get the primary settings form EEPROM
  Display.Initialize(Settings.isSoftRestart(), !oled_i2c_present);
  if(Settings.isSoftRestart()) {   // A soft restart does not show the TimesStampClassme screen, so it
    Settings.clearSoftRestart();   // simulates an impression of a dynamically change of player.
    Settings.Play = 1;             // After a soft restart, we start playing immediately (Note: BT always starts immediately)
    if(Settings.NV.SourceAF == SET_SOURCE_WEB_RADIO) {
      SsidSettings.EepromLoad();
      UrlSettings.EepromLoad();
      if(Settings.NV.TotalSsid == 0 || Settings.NV.WebRadioTotalStations == 0)
        ReadSetupFromCard();
    }
    if(Settings.NV.SourceAF == SET_SOURCE_SD_CARD)
      ReadSetupFromCard(); // (Re)load the track list
  }
  else {
    TimeStamps.Update();
    uint32_t timestamp_now = TimeStamps.GetStamp10ms();
    Display.ShowWelcome(); 
    if(Settings.NV.SourceAF == SET_SOURCE_WEB_RADIO) {
      SsidSettings.EepromLoad();
      UrlSettings.EepromLoad();
    }
    ReadSetupFromCard();
    while(TimeStamps.GetStamp10ms() < timestamp_now + 300)  // Show welcome screen at least 3 seconds
      TimeStamps.Update();
    Settings.Play = Settings.NV.SourceAF == SET_SOURCE_BLUETOOTH; // Bluetooth is always "autoplay"
  }
  Settings.SetLoopFunction(SettingsLoopFunction);
  delay(50);
  Scan_I2C(Wire, 0);
  if(oled_i2c_present)
    Scan_I2C(Wire1, 1);
  Display.ShowBaseScreen(Settings.Play ? DISPLAY_HELP_PLEASE_WAIT : DISPLAY_HELP_PRESS_PLAY_TO_START);
  Serial.printf("Current player is \"%s\"\n", Settings.GetSourceName());
  Player.Start(Settings.Play);

  if(Settings.Play == 1 || Settings.NV.SourceAF == SET_SOURCE_BLUETOOTH) {
    Settings.FirstTime = 0;
  }
  else {
    Serial.println("Press \"Play\" to start");
    Display.ShowPlayPause(Settings.Play);
  }
  GuiInit();
}

//=====================================================================//
//== Main Loop                                                       ==//
//=====================================================================//

void loop(void) {
  static unsigned run_time = 0;

  TimeStamps.Update();
  if(TimeStamps.GetSecondTick()) {
    Settings.EepromStore();
  }
  if(TimeStamps.Get4SecTick()) { 
    Housekeeping();
  }

  Player.loop(TimeStamps.Get10msTick(), TimeStamps.GetSecondTick()); // runs also audio.loop() if applicable
  //Button logic
  SW1.tick();
  SW2.tick();
  SW3.tick();
  SW4.tick();
  SW5.tick();
  GUI_Handler(KEY_NONE);
  //Serial port commands
  if (Serial.available()) {
    String r = Serial.readStringUntil('\n');
    parse_command(r);
  }
}

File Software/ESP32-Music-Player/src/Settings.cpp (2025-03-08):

#include <arduino.h>
#include <Wire.h>
#include <WiFi.h>
#include <stdlib.h>
#include "Settings.h"
#include "Version.h"
#include "Hardware/board.h"

#define NvData        ((unsigned char *)&NV)
#define NvMirrorData  ((unsigned char *)&NvMirror)


#if EEPROM_I2C_ADDRESS_SIZE == 1
  #error THIS APPLICATION ACCEPS ONLY EEPROMS >= 32K
#endif

#ifdef USE_SD_MMC 
  #define SD_BEGIN() SD_MMC.begin("/sdcard", true)
  #define SD_OPEN    SD_MMC.open
  #define SD_END     SD_MMC.end
#else
  #define SD_BEGIN() SD.begin(PIN_SPI_SS, SPI, SPI_SD_SPEED)
  #define SD_OPEN    SD.open
  #define SD_END     SD.end
#endif

#if 1

const char * const s_not_printable = "[Not Printable]";
const char * const s_none          = "[None]";

const uint8_t wifi_power_table[SET_WIFI_TX_MAX + 1] = {
  WIFI_POWER_19_5dBm,       // 78
  72, //WIFI_POWER_19dBm,   // 76 actual WIFI_POWER_18dBm = 72
  66, //WIFI_POWER_18_5dBm, // 74 actual WIFI_POWER_16_5dBm = 66
  //WIFI_POWER_17dBm,       // 68
  WIFI_POWER_15dBm,         // 60
  WIFI_POWER_13dBm,         // 52
  WIFI_POWER_11dBm,         // 44
  WIFI_POWER_8_5dBm,        // 34
  WIFI_POWER_7dBm,          // 28
  WIFI_POWER_5dBm,          // 20
  WIFI_POWER_2dBm,          // 8
};

//=======================================================
// Helper functions
//=======================================================

static int SD_read_line(File &f, char * dest, int n) {
  memset(dest, 0, n);

  // See: https://stackoverflow.com/questions/65621607/read-line-by-line-in-file-and-store-into-string-flash-data-saving-spiffs
  int len = f.readBytesUntil('\n', dest, n);
  if (len && dest[len - 1] == '\r')
    dest[--len] = '\0'; // If a '\r' is present, remove it!
  return len;
}

#if 1
static void HEXR(uint8_t s[], int n) {
  for(int i = 0; i < n; i++)
    Serial.printf("%02X",s[i]);
  Serial.println();
}
#else
  #define HEXR(a,b)
#endif

#if 0
static void HEXP(uint8_t s[], int n) {
  for(int i = 0; i < n; i++)
    Serial.printf("%02X",s[i]);
  Serial.println();
}
#else
  #define HEXP(a,b)
#endif

inline static int Validate(int val, int min, int max, int def) {
  if(val < min || val > max)
    return def;
  return val;
}
inline static int Validate(int val, int min, int max) {
  if(val < min)
    return max;
  if (val > max)
    return min;
  return val;
}

TwoWire & EEPROM_I2C_PORT(void) { return *Settings._wire; }

#define WIRE EEPROM_I2C_PORT()

static void Read24Cxx(int addr, uint8_t * dat, int len) {
#if EEPROM_I2C_ADDRESS_SIZE == 2 // Only for 24C32 and larger
  WIRE.beginTransmission(EEPROM_I2C_DEVICE);
  WIRE.write(addr >> 8);
  WIRE.write(addr & 0xFF);
  if( WIRE.endTransmission() != 0) return;
  for(int i = 0; i < len; i+= 64) {
    if(len-i >= 64) {
       WIRE.requestFrom(EEPROM_I2C_DEVICE, 64, (int)(len-i == 64));
       WIRE.readBytes(&dat[i], 64);
    }
    else {
      WIRE.requestFrom(EEPROM_I2C_DEVICE, len-i, 1);
      WIRE.readBytes(&dat[i], len-i);
    }
  }
#endif
}

static void Read24Cxx(int page, int addr, uint8_t * dat, int len) {
#if EEPROM_I2C_ADDRESS_SIZE == 1
  WIRE.beginTransmission(EEPROM_I2C_DEVICE | (page & 7));
  WIRE.write(addr);
  if(WIRE.endTransmission() != 0) return;
  WIRE.requestFrom(EEPROM_I2C_DEVICE| (page & 7), len, 1);
  WIRE.readBytes(dat, len);
#else
  WIRE.beginTransmission(EEPROM_I2C_DEVICE);
  WIRE.write(page);
  WIRE.write(addr);
  if(WIRE.endTransmission() != 0) return;
  WIRE.requestFrom(EEPROM_I2C_DEVICE, len, 1);
  WIRE.readBytes(dat, len);
#endif
}

static void Write24Cxx(int page, int addr, uint8_t dat) {
  #if EEPROM_I2C_ADDRESS_SIZE == 1
    WIRE.beginTransmission(EEPROM_I2C_DEVICE | (page & 7));
  #else
    WIRE.beginTransmission(EEPROM_I2C_DEVICE);
    WIRE.write(page);
  #endif
  WIRE.write(addr);
  WIRE.write(dat);
  if(WIRE.endTransmission() != 0) return;
  delay(5);
}

static void Write24CxxPage(uint16_t addr, uint8_t * dat) {
  addr /= EEPROM_PAGE_SIZE; // Place on page boundary
  addr *= EEPROM_PAGE_SIZE;
  DEBUG_MSG_VAL("Writing EEPROM page at 0x%04X : ", addr);
  HEXR(dat, EEPROM_PAGE_SIZE);

  #if EEPROM_I2C_ADDRESS_SIZE == 1
    WIRE.beginTransmission(EEPROM_I2C_DEVICE | ((addr >> 8) & 7));
  #else
    WIRE.beginTransmission(EEPROM_I2C_DEVICE);
    WIRE.write(addr >> 8);
  #endif
  WIRE.write(addr & 0xFF);
  WIRE.write(dat, EEPROM_PAGE_SIZE);
  if(WIRE.endTransmission() != 0) return;
  delay(5);
}

// Write each byte individually. Optimizing is possible, but then you must consider the
// page size of the EEPROM. Page size could be 8,16,32,64,128 bytes. See datasheet for info.
static void Write24Cxx(int page, int addr, uint8_t * dat, int len) {
  for(int i = 0; i < len; i++)
    Write24Cxx(page, addr+i, dat[i]);
}

//==============================================================================
// Main settings
//   - NV stored in EEPROM page 0 @ 0x00-0x7F
//==============================================================================
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

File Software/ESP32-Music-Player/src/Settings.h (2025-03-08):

#ifndef _SETTINGS_H_
#define _SETTINGS_H_

#include <stdint.h>
#include <Wire.h>

#include "Hardware/board.h" // For macro USE_SD_MMC

#ifdef USE_SD_MMC
  #include <SD_MMC.h>
#else
  #include <SD.h>
#endif

//=======================================================
// EEPROM specification
//=======================================================

#define BT_DEVICE_NAME   "ESP32 Music Player"

#define EEPROM_TYPE      64 // 24Cxx where xx is EEPROM_SIZE
#define EEPROM_PAGE_SIZE 32 // in bytes, check datasheet for value

#if EEPROM_TYPE <= 16
  #define EEPROM_I2C_ADDRESS_SIZE     1  // 1 for 24C02 through 24C16
#else
  #define EEPROM_I2C_ADDRESS_SIZE     2  // 2 for 24C32 and larger
#endif

#if EEPROM_TYPE == 0
  #define EEPROM_SIZE        64
  #define EEPROM_BLOCK_SIZE  64
#elsif EEPROM_TYPE == 1
  #define EEPROM_SIZE       128
  #define EEPROM_BLOCK_SIZE 128
#else
  #define EEPROM_SIZE (256 * EEPROM_TYPE / 2)
  #if EEPROM_I2C_ADDRESS_SIZE == 1
    #define EEPROM_BLOCK_SIZE 256
  #else
    #define EEPROM_BLOCK_SIZE EEPROM_SIZE
  #endif

#endif

#define EEPROM_I2C_DEVICE         0x50
#define EEPROM_I2C_CLOCK_SPEED  100000  // Some EEPROMs work only at 100kHz

#define EEPROM_SETTINGS_PAGE         0
#define EEPROM_SETTINGS_ADDR         0

//=======================================================
// Main settings
//   - NV stored in EEPROM page 0 @ 0x00-0x7F
//   - Make sure sizeof(NV) stays below 128
//=======================================================

#define SET_SOURCE_MIN            0
#define SET_SOURCE_MAX            3

#define SET_SOURCE_SD_CARD        0
#define SET_SOURCE_WEB_RADIO      1
#define SET_SOURCE_WAVE_GEN       2
#define SET_SOURCE_BLUETOOTH      3
#define SET_SOURCE_DEFAULT        SET_SOURCE_SD_CARD

#define SET_WAVE_FORM_MIN         0
#define SET_WAVE_FORM_MAX         4 //3: only waveforms, 4: plus DAC test, 6: plus DAC debug
#define SET_WAVE_SINE_440HZ       0
#define SET_WAVE_SINE_1KHZ        1
#define SET_WAVE_TRI_440HZ        2
#define SET_WAVE_TRI_1KHZ         3
#define SET_WAVE_DEFAULT          SET_WAVE_SINE_440HZ

#define SET_SSID_MAX               3  //max 4 networks

#define SET_WIFI_TX_MAX            9  // max wifi tx level (index)
#define SET_WIFI_TX_DEFAULT        0  // Points to highest level

#define SET_BT_TX_MAX              7  // max bluetooth tx level (index)
#define SET_BT_TX_DEFAULT          5  // +3dbm 

#define SET_WEBRADIO_MAX         199  // By far enough
//#define SET_SD_TRACKS_MAX        299 // should be by far enough
//#define SET_SD_TRACKS_MAX        99  // should be by far enough
#define SET_SD_TRACKS_MAX        5000  // should be by far enough
#define SET_SD_TRACKS_SIZE      5000//10000  // should be enough for about 200 tracks, depending on the lengths of the file names
#define SET_SD_TRACKS_PS_SIZE  128000  // should be enough for about 2500 tracks, depending on the lengths of the file names

#define SET_SOFT_RESET_MAGIC     0x5A    //  If this is set, the reset procedure will be different.

// Use the same values as Audio class, see:
// https://github.com/schreibfaul1/ESP32-audioI2S/wiki#how-to-adjust-the-balance-and-volume
#define SET_VOLUME_MIN          1
#define SET_VOLUME_MAX         21
#define SET_VOLUME_DEFAULT      7

typedef struct {
#pragma pack(1) // place at 8 bit boundaries
  uint16_t Version;         // 
  uint8_t  SourceAF;        // 0 = SD-Card, 1 = web radio, 2 = Tone generator, 3 = Bluetooth audio
  uint8_t  CurrentSsid;     // 0,1,2,3:  We can connect to up to four wifi access points
  uint8_t  TotalSsid;       // Valid number of SSISs
  uint8_t  MagicKey;        // When set to SET_SOFT_RESET value, the ESP32 wil perform a restart.
  uint8_t  WaveformId;      // See "SimpleWaveGenerator.h" for the list of wave forms
  uint8_t  WifiTxIndex;     // Index in wifi tabel with TX levels
  uint8_t  BtTxIndex;       // Index in bluetooth tabel with TX levels
  uint8_t  Subversion;      // expansion of Version
  uint16_t DiskTotalTracks;
  uint16_t DiskCurrentTrack;
  uint32_t DiskTrackResumeTime;
  uint32_t DiskTrackResumePos;
  uint32_t DiskTrackTotalTime;
  uint16_t WebRadioCurrentStation;
  uint16_t WebRadioTotalStations;
  uint8_t  Volume;         // Volume settings only for debugging puposes;
  uint8_t  VolumeSteps;
  uint8_t  OutputFormat; 
  uint8_t  BtName[32];
#pragma pack()
} NvSettings_t;
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

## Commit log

2024-09-03 Clarification for Freenove ESP32-Wrover CAM Board V3.0
    [ESP32-MUSIC-PLAYER-V1.kicad_sch]
2024-09-18 Renamed V24 to Vin
    [ESP32-MUSIC-PLAYER-V1.kicad_pcb, ESP32-MUSIC-PLAYER-V1.kicad_sch]
2024-09-20 Fixed BT Volume control
    [Settings.cpp, Settings.h]
2024-10-04 Suppress showing ".mp3" entension in SD track titles
2024-10-04 Improved track and URL search
2024-11-02 Updated SSD1306 drivers
    Added support for SPI version OLEDs, and some bugfixes
    [Board.h, Display.cpp, ESP32-Music-Player.ino]
2024-11-09 Updated SPI display support
    Updated SPI drivers. Fixed SPI - Wifi interference bug.
    [Board.h, Display.cpp, ESP32-Music-Player.ino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]
2024-11-09 Accidentally uploaded wrong files
    Now the files are the right ones.
    [Board.h, Display.cpp, ESP32-Music-Player.ino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]
2024-12-20 Set i2c as default display interface
    Current hardware supports i2c OLED only. Default was accidentally set to SPI. Changed to i2c.
2024-12-29 Fixed ticker in SSD1306 driver, fixed OLED rotation
    [Board.h]
2025-02-23 New version with SPI version of 2.4" OLED module
2025-02-23 New version with SPI version of 2.4" OLED module
    Note: this version uses SMD 1206 components.
    [ESP32-MUSIC-PLAYER-MINI-V5-PANEL.kicad_pcb, ESP32-MUSIC-PLAYER-MINI-V5-Strapubox.kicad_pcb, ESP32-MUSIC-PLAYER-MINI-V5-Strapubox.kicad_sch]
2025-02-23 Fixed silkscreen location for SW5
    [ESP32-MUSIC-PLAYER-MINI-V5-Strapubox.kicad_pcb]
2025-02-23 New OLED driver, and support for SPI OLED
    OLED driver now supports proportional fonts. In addition, sketch automatically detects if OLED is on I2C or on SPI bus.
2025-03-01 Expanded SSD1306_FONT_5X8_PROP with code page 437
    Also fixed some minor bugs
    [Display.cpp, Player.cpp]
2025-03-01 Example web station file
    Add to the SD Card, insert the card in the ESP32 Music Player, and reboot the player/
2025-03-08 Added limited support for UTF-8 character strings
    Also did some bug fixes
    [Settings.cpp, Settings.h]
2025-08-25 Added some 3D images of assembly with main PCBA
2025-08-31 Added schematics in PDF
    [ESP32-MUSIC-PLAYER-MINI-V5-Strapubox.kicad_sch]
2026-10-18 Update Espressif arduino-esp32 3.3.10
    Compile with Espressif arduino-esp32 3.3.10 or lower (3.3.x);
    Note: Espressif latest (3.3.11 & 3.3.12) overflows IRAM by 184 bytes
    Also uses audioI2S version 4.0.0g
2026-10-23 Added support for I2C display
